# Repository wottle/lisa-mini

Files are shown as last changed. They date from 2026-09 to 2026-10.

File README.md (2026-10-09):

# Lisa Mini

A 3D-printable, Apple Lisa–inspired enclosure for building a mini all-in-one
around a [LisaFPGA](https://www.tindie.com/products/lisafpga/) board and an
11.6" 1080p widescreen LCD panel.

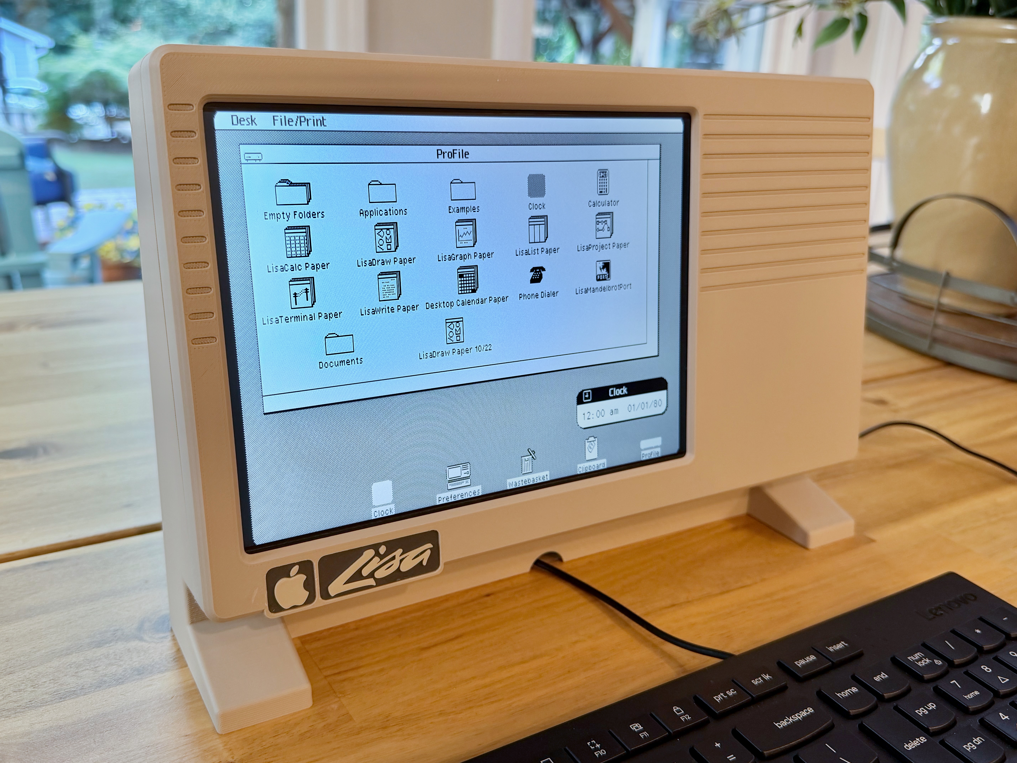
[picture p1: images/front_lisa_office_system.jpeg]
Lisa Mini running Lisa Office System


| | |
|---|---|
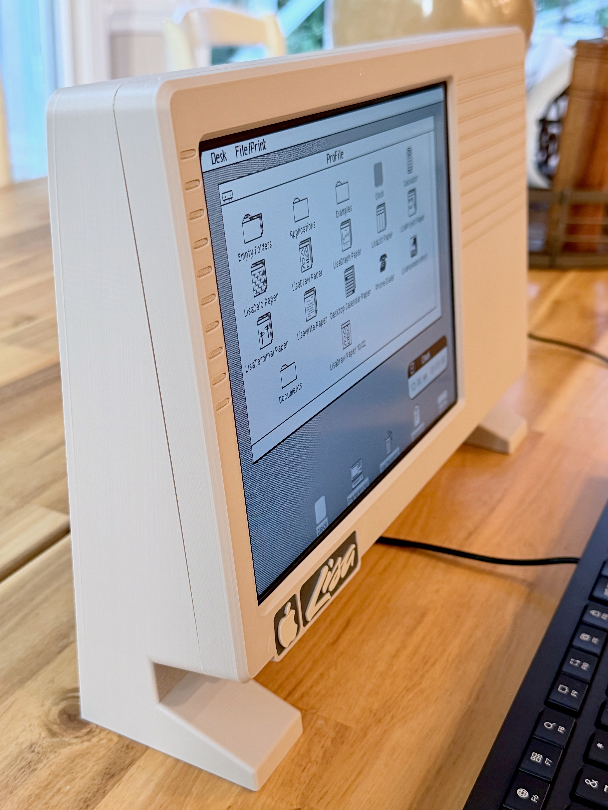
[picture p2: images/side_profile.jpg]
Side profile
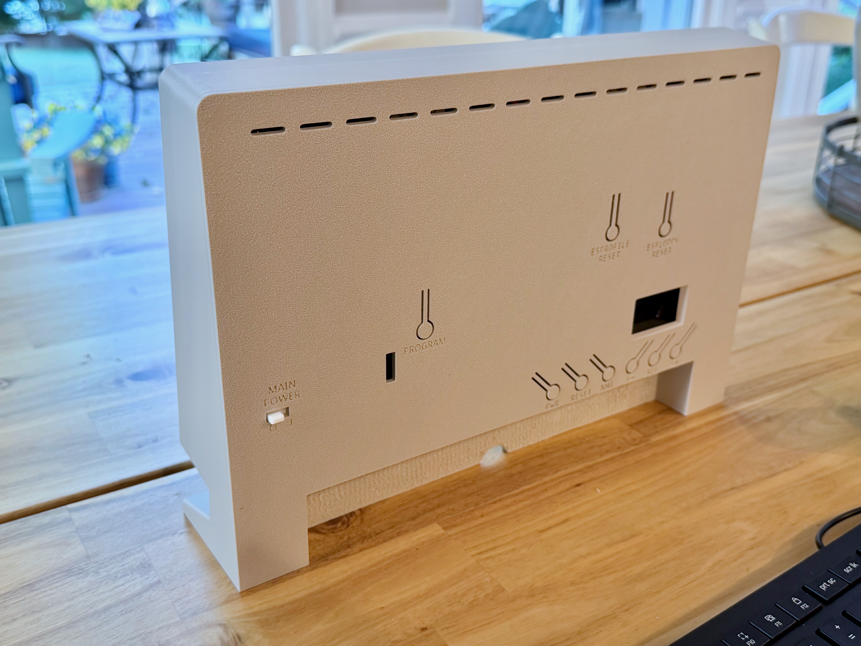
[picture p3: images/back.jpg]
Back, with labeled controls
|  |  |
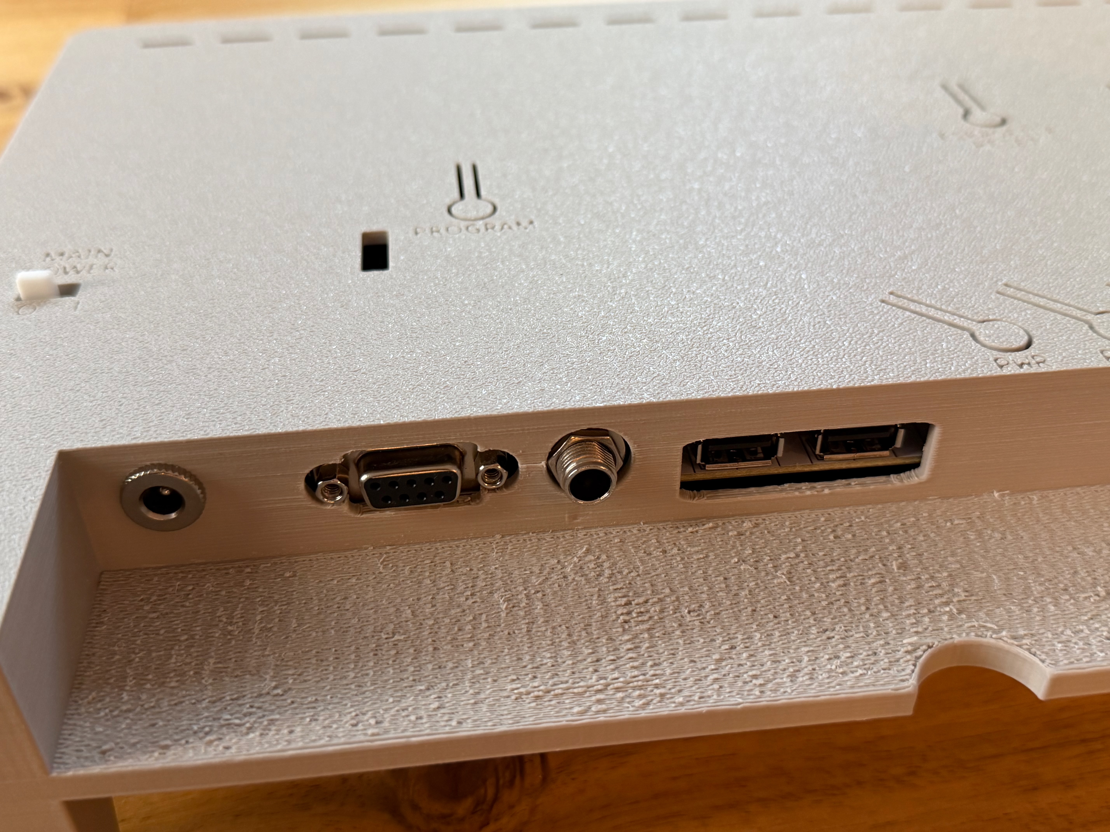
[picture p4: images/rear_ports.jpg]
Rear I/O
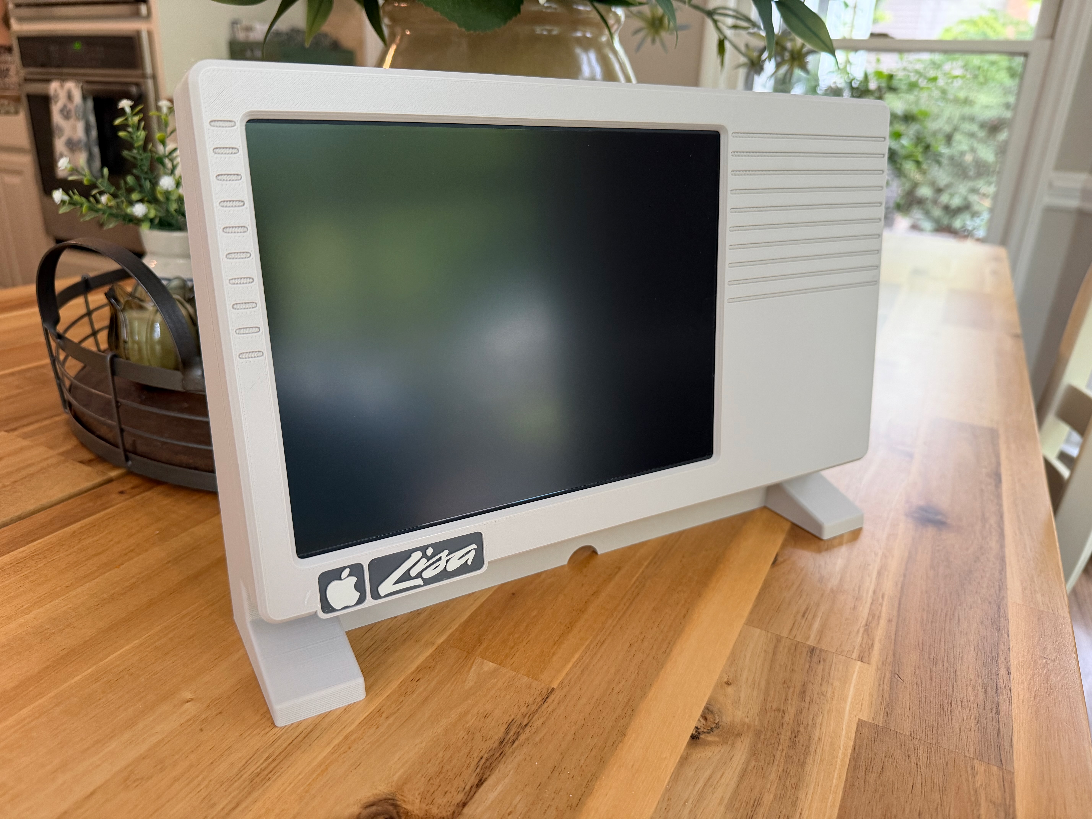
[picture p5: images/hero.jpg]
Angled front view
|  |  |

## About

This case is designed to house a LisaFPGA board — an FPGA-based
re-implementation of the original Apple Lisa — behind a compact modern LCD,
in an enclosure that echoes the look of the original 1983 Lisa: front vent
lines, a screen that leans back while the case stays vertical, and integrated
L-shaped feet with no visible seams between leg and case.

Designed for FDM printing, optimized to minimize supports where possible —
though both the front and back shells currently do need some supports
(see [Printing](#printing) below).

There's no built-in FloppyEmu, because the LisaFPGA has a floppy emulator
built in (ESFloppy) — no separate hardware needed. There are two designs
(see [Choose your design](#choose-your-design)). The stock one leaves the
LisaFPGA untouched and has cutouts for the ESFloppy control buttons and a
window to see the screen from the back, dressed up with a shroud
(`Lisa_Mini_ESFloppy_Shroud.obj`) since that opening sits well below the
back surface. The shroud's fit isn't perfect — it exposes a bit too much of
the area below the ESFloppy LCD, and needs some glue to stay in place. The
other design moves the ESFloppy screen and buttons, and the lit power
button, to the front, at the cost of soldering wires to the LisaFPGA.

## What's here

```
models/
  print-ready/
    common/      Parts printed for either design
    Lisa_Mini_With_ESFloppy_Screen_And_Buttons_On_Back/   Stock design: LisaFPGA left untouched
    Lisa_Mini_With_ESFloppy_Screen_And_Buttons_On_Front/  Front-mounted ESFloppy screen, buttons, and power button
  source/        Parametric OpenSCAD source + design notes
images/           Build photos and renders
docs/
  design_a/       ASSEMBLY.md and BOM.md for the ESFloppy-on-back design
  design_b/       ASSEMBLY.md and BOM.md for the ESFloppy-on-front design
  PRINTING.md     Slicer settings and printing notes
```

## Assembly video

Watch the [assembly video on YouTube](https://youtu.be/3yojjUhr7K4). It builds Design B, which
includes every step of Design A plus the ESFloppy and power button
modifications, so it works as a guide for either design.

## Choose your design

There are two versions of the case. **Pick one** and print its folder plus
the `common/` parts.

| | ESFloppy on back (stock) | ESFloppy on front |
|---|---|---|
| Folder | `Lisa_Mini_With_ESFloppy_Screen_And_Buttons_On_Back/` | `Lisa_Mini_With_ESFloppy_Screen_And_Buttons_On_Front/` |
| LisaFPGA modifications | None -- the board is left untouched | Solder wires to the ESFloppy buttons, move the ESFloppy screen, and move the lit power button to the front (remove the board's own power LED, solder wires to the board) |
| ESFloppy screen and buttons | Rear window and button cutouts, dressed up with a shroud | Front-mounted, with printed button caps and a screen clip |
| Power button | Button cutout on rear case | Lit button on the front, plus a master rocker power switch |
| Difficulty | Easier | Needs soldering to the LisaFPGA, plus extra parts (see BOM) |

## Parts to print

**Common parts (either design)** -- `models/print-ready/common/`

| File | Part |
|---|---|
| `Lisa_Mini_LCD_Mount_Clips.obj` | LCD retaining clips |
| `Lisa_Mini_Lisa_Logo_Plate.obj` | Lisa logo badge insert (see note below) |
| `Lisa_Mini_Manufacturer_Blank_Logo_Plate.obj` | Blank badge insert for the bezel's second holder (see note below) |
| `Lisa_Mini_Power_Switch.obj` | Cap over the LisaFPGA's power switch (the one that turns the whole device on and off) |
| `Lisa_Mini_Back_LisaFPGA_SD_Slot_Covers.stl` | SD slot covers for the back |

**ESFloppy on back** -- `models/print-ready/Lisa_Mini_With_ESFloppy_Screen_And_Buttons_On_Back/`

| File | Part |
|---|---|
| `Lisa_Mini_Front.obj` | Front bezel / LCD mount |
| `Lisa_Mini_Back_LisaFPGA.obj` | Rear shell, sized for the LisaFPGA board |
| `Lisa_Mini_ESFloppy_Shroud.obj` | Dresses up the rear ESFloppy screen opening, which currently sits well below the back surface |

**ESFloppy on front** -- `models/print-ready/Lisa_Mini_With_ESFloppy_Screen_And_Buttons_On_Front/`

| File | Part |
|---|---|
| `Lisa_Mini_Front_With_ESFloppy_Screen.obj` | Front bezel with the ESFloppy screen opening |
| `Lisa_Mini_Front_With_ESFloppy_Slot_Filler_Black.obj` | Black slot filler for the front |
| `Lisa_Mini_Back_LisaFPGA_ESFloppy_Moved_To_Front.obj` | Rear shell with no ESFloppy window or buttons |
| `Lisa_Mini_ESFloppy_Screen_Clip.obj` | Holds the ESFloppy screen |
| `Lisa_Mini_ESFloppy_Button_Cap.obj` | ESFloppy button cap |
| `Lisa_Mini_ESFloppy_Button_Inner_qty3.obj` | Button inner part (single part; print 3 copies) |
| `Lisa_Mini_ESFloppy_Button_Outer_qty3.obj` | Button outer part (single part; print 3 copies) |
| `Lisa_Mini_Power-Button.stl` | Front-mounted lit power button |

Each design has its own parts list and build guide: Design A
([BOM](docs/design_a/BOM.md), [assembly](docs/design_a/ASSEMBLY.md)) and
Design B ([BOM](docs/design_b/BOM.md), [assembly](docs/design_b/ASSEMBLY.md)).

**Logo plate note:** the front bezel has holders for two badge plates. This
repo includes the Lisa logo plate (`Lisa_Mini_Lisa_Logo_Plate.obj`) for one
and a plain, unbranded insert
(`Lisa_Mini_Manufacturer_Blank_Logo_Plate.obj`) for the other — deliberately
not shipping an Apple logo plate here to avoid distributing Apple's
trademarked logo. If you want an Apple logo in that spot, you'll need to
source or model your own.

## Editing the design

The parametric source (`models/source/lisa_modern_template.scad`) is an
OpenSCAD model of the case shell and covers the overall body/vent/leg
geometry. `models/source/lisa_design.md` documents the design reference
image this was built against and the reasoning behind the current shape —
read it before changing proportions.

Note: the `print-ready/` OBJs are further along than the `.scad` source
file. The OpenSCAD model produced a simplified starter shell, which was
then brought into TinkerCAD for significant additional work — mounting
points, port/switch openings, LCD clip geometry, and the logo plate —
that isn't reflected in the `.scad` file. Treat the `.scad` file as the
best starting point for overall shell/vent/leg proportions, not as a 1:1
source for the exact release files; there's currently no single parametric
source that captures the final printed geometry end to end.

## Software

The case's screen opening is sized for the original 9.7" 4:3 Lisa-style
window, but the LCD actually used is an 11.6" 1080p widescreen panel — the
image doesn't natively fill (or center in) that opening. This build
requires [wottle/LisaFPGA](https://github.com/wottle/LisaFPGA), a fork of
the LisaFPGA software that adds the ability to offset the displayed image
so it lands correctly within the case's opening. Stock LisaFPGA firmware
will not position the image correctly for this case.

**Flash it before assembling the case** — see "Before you start" in the
assembly guide for your design
([A](docs/design_a/ASSEMBLY.md#before-you-start),
[B](docs/design_b/ASSEMBLY.md#before-you-start)) for why.

## Power design notes

The original plan was to power the LCD controller board directly off a 5V
USB-C input. That controller board didn't work reliably on 5V USB-C — the
board was later damaged during troubleshooting, so it's unconfirmed whether
5V USB-C itself was the actual problem or just correlated with what killed
it. The working setup, and what the BOM/case now assume, is a single 12V
barrel jack input split across two buck converters into separate 5V lines
for the LisaFPGA and the LCD controller. If you try 5V USB-C directly into
the controller board, treat it as unverified and have a fallback plan.

The `Lisa_Mini_Power_Switch.obj` cap only switches the LisaFPGA — there's
no separate power switch for the LCD. The plan is to just pull the 12V
input when not in use, which cuts power to both.

## Printing

See [`docs/PRINTING.md`](docs/PRINTING.md). Quick summary:

- Wall thickness: ~2.4mm
- Infill: 15–20%
- Bed size: 350mm — the model is 330mm wide (front face down, back face up)
- Both front and back shells currently need supports — back for the skirt
  between the legs, front for the logo plate badge holder area
- Front/back shells press-fit together (alignment bumps, no screws);
  everything else uses M3x4mm screws

## License

Design files are released under
[CC BY-NC-SA 4.0](https://creativecommons.org/licenses/by-nc-sa/4.0/) —
free to share and remix for non-commercial use, with attribution, under the
same license. See [`LICENSE`](LICENSE).

## Also published on

- [Thingiverse](https://www.thingiverse.com/thing:7406982)
- [Creality Cloud](https://www.crealitycloud.com/model-detail/6aa08dfae6a4b4ead4eae24b?profileId=6aa08dfae6a4b4ead4eae251)

Not published to MakerWorld/Bambu — no Bambu printer currently has a bed
large enough for the 330mm-wide front/back shells.

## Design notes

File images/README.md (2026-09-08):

# Images

Drop photos and renders here:

- `hero.jpg` — main photo referenced from the top-level README
- Build/assembly photos referenced from `docs/ASSEMBLY.md`
- Render angles (front, 3/4, side profile, rear) for reference

Keep large source photos out of git history where possible (resize for web
before committing) — this repo has no LFS configured.

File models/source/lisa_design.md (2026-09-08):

# Lisa Mini — Design Reference

Source image: `lisa_design.png` (four views: front 3/4, angled front, side
profile, rear). This file captures what that image specifies, and how the
OpenSCAD model (`lisa_modern_template.scad`) maps to it, so future edits can
check back against the original intent instead of just the current code.

## Spec sheet (as stated in the image)

- **Width:** 330 mm (13.0 in)
- **Height:** 240 mm (9.4 in)
- **Depth:** 95 mm (3.7 in)
- **Weight (est.):** ~1.1 kg (2.4 lb)

**Design features called out in the image:**
- 9.7" 4:3 LCD (iPad panel), ~197×148mm visible area
- Inspired by the original Apple Lisa
- Optimized for 3D printing
- Minimal parts, no visible joins
- Front vent lines preserved
- Single PCB mount
- Integrated stand (legs)
- FloppyEmu slot (optional, not modeled)

**Printing notes called out in the image:**
- Designed for FDM printing
- No overhangs > 45°
- Snap-fit or screw assembly
- Wall thickness: 2.4mm
- Infill: 15–20% recommended

## What the image actually shows (visual detail, since dimensions alone
don't capture the shape)

- **Front:** screen roughly centered-left, with short horizontal vent
  ticks in a narrow strip on the left of the screen, and a noticeably
  wider block of the same vent lines on the right of the screen. Rainbow
  Apple logo bottom-right of the bezel (not modeled — decorative decal,
  out of scope). Vent lines start about level with the top of the screen
  and run for roughly the screen's upper half — they don't span the full
  case height.
- **Side profile:** the whole unit reads as a wedge — deep flat base at
  the feet, narrowing toward the top. Critically, the *screen leans back*
  (like the original Lisa's CRT housing) while the *back panel stays
  vertical*. The foot is clearly an L-shape: a slim, tapering riser
  attached under the case, meeting a flat pad that reaches forward along
  the floor — not a simple wedge or cone.
  - Now that the model's front actually leans back per the tilt fix, the
    case's real proportions (`body_depth_bottom=80`, `body_depth_top=45`,
    `case_height=189` currently) are shallower than the image's stated
    330×240×95 — see "Deliberate deviations" below.

### Legs: seamlessness is the critical detail

In the reference image, the leg is **not a bolted-on foot** — each side
panel of the case reads as *one continuous piece* that simply keeps going
past the bottom of the electronics housing, all the way to the floor, with
a subtle forward flare only right at the base (where it steps out from
under the case's own front-bottom overhang). There is no separate "foot"
element visually distinguishable from the case's own side — no step, seam,
or change of plane anywhere along that edge, front or back. This is the
single biggest reason the reference reads as "Lisa-like" rather than
"generic monitor stand": a leg that is numerically positioned to *match*
the case's dimensions still reads as an attached accessory if it's built
as an independent part; only a leg that *is* the case's own geometry,
merely continued, reads as seamless.

**First attempt (superseded):** anchored a separately-shaped L-bracket
(flat pad + tapered riser, its own independent width/depth parameters) so
its back face lined up with the case's rear-plane Z depth. This fixed the
back-face gap but still looked like "a leg" rather than "the case's own
side" — narrower than the case, inset from its edges, with its own corner
radius and taper rate that had to be separately chosen and matched. The
result was correct by the numbers but still visually read as a separate
part, which is exactly the complaint this section exists to prevent.

**Current approach:** the leg is a left/right edge strip of the case's own
outer shell, sliced to `feet_width` at each edge via `leg_side_shape()`,
continued from the case's own y=0 down to the floor — and — critically —
built and called *from inside the same `body_tilt()` rotation as the case
itself* (see `rear_shell()`). Because it shares the case's width reference
(flush with the case edges, no inset) and rotation, there is no separate
shape to keep in sync — the leg's continuity with the case is guaranteed
by construction, not by matching numbers. The forward flare "under the
protruding screen" falls out of the rotation for free: points below the
case's own y=0 rotate to increasingly negative Z (more forward) as they go
down, since the tilt pivots on the case's front-bottom edge.

**Wrinkle 1 (fixed): floor contact wasn't actually flush.** Rotating the
leg the same way as the case means its underside is no longer level (the
same rotation that tilts the screen back also tilts the leg's floor
contact, sagging the back lower than the front). The first attempt at
`required_lift()` computed the exact lift that puts the leg's lowest point
(the back-bottom corner) precisely at y=0 -- which sounds right, but means
the clip-to-floor intersection has *nothing left to cut*: the leg's
underside just grazes the floor at that one back corner, with the rest of
the underside (most visibly the front) tilted up in the air above it,
15mm+ in the numbers this was caught at. The fix: decouple how deep the leg
is *built* from where it's *lifted to*. `leg_side_shape()` now builds each
leg `feet_height + leg_extra_reach` deep (deliberately well past the
intended floor), `required_lift()` simply sets the case's front-bottom
pivot edge (the one point `body_tilt()` never moves) `feet_height` above
the floor, and `rear_shell()`'s y≥0 clip then slices through *solid*
material across the whole leg footprint -- verified by exporting
`rear_shell()` alone and confirming the vertices at the true minimum Y
span each leg's full width (`x: 0-40` and `290-330`, not a single point),
i.e. a genuine flat cut, not a corner graze.

**Wrinkle 2 (fixed): rounding doubled up at the seam.** `leg_side_shape()`
originally reused the case's own `rounded_prism` (same `corner_radius`),
which rounds the leg's own top edge right where it meets the case --
directly on top of the case's own bottom-corner rounding, at the same Y.
Two independently-rounded corners stacked at one seam reads as a pinched
double-curve rather than one clean transition. Fixed by dropping rounding
from the leg entirely (a plain `cube()`, no radius) and raising it up by
`leg_overlap` (`corner_radius + 0.2`) past the case's own y=0, so the
leg's sharp material fills in solid over the case's rounded corner instead
of showing its own curve there -- the only rounding left along that edge
is wherever the case is rounded on its own (its top corners), unrelated to
the leg. `tilt_angle()` was pulled out of `body_tilt()` into its own
function so `required_lift()` and `leg_side_shape()` can't drift out of
sync with the case's own tilt.

**The L profile itself.** Up to this point the leg was still a solid
block (flush back, flush width, floor-clipped, seam-hidden -- but no
notch). Giving it the actual L shape means cutting away the top-front
mass, per this shape (constant across the leg's width, via
`notch_profile()`):
- A **riser** segment at the back, `leg_riser_depth` thick, running from
  the case down by `leg_riser_drop`. Built as a plain constant-Z cut (no
  trig at all): since the whole leg shares the case's own `body_tilt()`
  rotation, any constant-Z segment automatically stays parallel to the
  case's own tilted front after that shared rotation -- it can't help but
  match the display's angle.
- A **bend-to-foot** segment continuing down by `leg_toe_drop` to the
  foot's front tip, meant to read as `leg_foot_slope` degrees below
  horizontal in the *final*, post-tilt view. This one isn't free: a
  locally-horizontal cut does not come out horizontal after the same
  rotation that tilts the display -- it comes out sloped at exactly
  `tilt_angle()` from horizontal, since the rotation tips whatever's
  locally flat right along with everything else. Solving for the local
  slope that cancels that and adds the requested tilt gives a clean
  closed form: `local_slope = tan(tilt_angle() + leg_foot_slope)` (derived
  via the angle-addition identity; `leg_foot_slope=0` would give a
  perfectly level result).
- Below the toe, the cross-section is constant again, straight down
  through the floor (with `leg_extra_reach`'s overshoot for the floor
  clip, unchanged from before).

Implementation note: since `polygon()`/`linear_extrude()` can only extrude
along OpenSCAD's own Z axis, and this profile needed to run along the
leg's *width* (X) instead, `leg_side_shape()` defines the profile in
`[Y, Z]` pairs and remaps axes with `rotate([0,90,0]) rotate([0,0,90])` so
the final solid comes out as `(X, Y, Z) = (extrude parameter, Y, Z)` --
verified against an isolated test polygon (checking the exact X/Y/Z value
sets in the exported STL) before relying on it, since an axis-remap
rotation is an easy place to silently mirror or scramble a shape.

**Wrinkle 3 (fixed): the leg's back edge wasn't flat.** The notch
profile's back edge was a plain constant-Z cut, same trick as the riser
segment above (see riser bullet) — which is exactly the problem: that
trick relies on staying *parallel* to the case's front face after
rotation, but the case's actual rear panel is supposed to come out **flat**
(perpendicular to the floor, not parallel to the tilted front — see item
5 in the log below). A constant-Z leg-back only coincides with that flat
plane at the pivot (y=0); moving up the leg's height, it drifts further
off, parallel to the front's tilt instead. Fixed the same way as Wrinkle
1 (floor contact): overshoot first, then clip flush in the *global*
frame. `leg_rear_extra_reach` pushes the back edge deep enough that
`rear_plane_z()` — the global Z where the case's own tapered rear face
lands after `body_tilt()` (`body_depth_bottom * cos(tilt_angle())`, since
that's precisely the rotation that flattens the taper line into a flat
plane) — always cuts through solid material, never grazing a corner.
Verified by exporting `rear_shell()` alone and confirming every leg-back
vertex collapses to that single Z value rather than a spread of values.

**Rounded the leg's exposed edges — profile corners AND side caps.** The
knee (where the riser bends into the foot), the foot's front tip, and the
leg's left/right side faces (both the riser's and the foot's) were all
sharp — reads as "cut out of a block" rather than a finished part, and
sharp edges print worse than filleted ones. First pass only rounded the
knee/toe (via the same dilate/erode `offset()` trick as `rounded_2d()`,
applied to the 2D notch polygon) since that only rounds edges that run
*along* the extrusion axis (X, the leg's width) — it can't touch the
edges at the leg's two ends, where those front faces meet the flat
side-cap planes.

Rounding the side-cap edges too needs an actual 3D fillet, done via the
standard "erode along X, then `minkowski()` with a sphere" rounded-box
trick: build the core extrusion inset by `leg_edge_round` on each end
(`feet_width - 2r` wide, shifted in by `r`), then `minkowski()` it with
`sphere(r)`. For any of the core's flat faces, minkowski with a sphere
just offsets that face outward along its own normal by `r` — so insetting
by `r` first and growing by `r` after lands the two side caps back at
exactly `x=0`/`x=feet_width` (no residual bulge needing a clip), while
every edge/corner in between — the knee, the toe, *and* now the side-cap
edges — comes out genuinely filleted, all from one `leg_edge_round`
radius. This replaced the earlier 2D-only `rounded_notch_2d()` /
`offset()` approach entirely (real 3D rounding subsumes it; using both
would double up).

The back (rear-plane) and floor edges are deliberately left un-inset —
minkowski still puffs them outward by `r` too, but that's harmless: as
established above, they're already overshoot material clipped exactly
flush by the global half-space cuts regardless of the shape fed into
them, and the existing margins (`leg_extra_reach`, `leg_rear_extra_reach`)
comfortably exceed `leg_edge_round`. Verified both that the fillets show
up correctly (rendered close-ups of a single leg and of the assembly) and
that the floor/back flush cuts survived unchanged (re-checked the
exported STL: the leg's back face is still a single flat Z value, and the
floor contact is still a full-width flat patch, just with its two front
corners now rounded instead of square).
- **Rear:** flat vertical panel, full-width row of short horizontal vent
  slats near the top, and a lower recessed strip for Mouse / Keyboard /
  USB ports and their labels, plus the feet visible at the base. The model
  currently stands in for that lower strip with a plain rectangular I/O
  bay (`io_bay_*` params) rather than modeling individual ports/labels —
  see item 15 below; real port cutouts and labels are meant to return once
  the board layout is designed.
- **Corners:** rounded on every visible edge, front and back consistently
  (not just the front bezel).
- **No chin, no visible seam** at the bottom of the screen bezel — the
  image's front face is one continuous surface from top to bottom.

## How the model maps to this (session history, newest last)

1. **Base template → resized to spec.** Started from a generic flat-front
   Lisa-style starter template (`lisa_modern_template_README.txt`
   describes the original). Resized to 330mm width, adjusted height, and
   widened/repositioned the right vent grille to match "narrow left,
   wide right."
2. **Wedge body + tapered legs.** Replaced the flat-depth body with a
   tapered shell (deep at the floor, shallow at the top) and tapered fin
   feet, to get the wedge silhouette from the side-profile image.
3. **Fixed a real bug:** `rounded_2d()`'s `offset(r=r)` /
   `offset(delta=-r)` rounding pattern silently produces empty geometry
   when `r` equals exactly half the shape's narrow dimension — meaning no
   vent slots were ever actually being cut in the original template. Fixed
   by keeping rounding radii strictly under half the narrow dimension.
4. **Corrected vent/screen left-right mapping and case proportions.**
   Rendering with a camera matching the actual OpenSCAD viewing angle
   showed the vent widths were swapped from the image (wide should be
   right, narrow left) and the case was much taller than the screen
   needed — fixed both, and later renamed the vent variables so their
   names match their actual rendered side.
5. **Front tilts back, rear stays flat — via rotation, not shear.** The
   image's screen leans back while the back panel is vertical. A Z-only
   shear achieves the lean but leaves the top/bottom caps perpendicular
   to the *original* vertical axis instead of to the tilted front, which
   looked glued-on. Switched to a true rotation (`body_tilt()`) pivoting
   on the front-bottom edge, which keeps the top/bottom faces
   perpendicular to the tilted front (matching the image's continuous
   surface) while the rear stays flat, by construction (same taper rate
   that tilts the front by the right amount also cancels the rear's
   slope to zero).
6. **Removed the chin, unified corner rounding.** The template had a
   protruding lower "chin" not present in the reference image, and the
   rear shell rounded a different plane than the front bezel (so corners
   didn't match front-to-back). Removed the chin; rebuilt the rear
   shell's taper as a full rounded box trimmed by an unrounded wedge
   cutter, so it shares the front bezel's exact corner rounding.
7. **Chamfered the screen opening's front edge** — a detail not visible
   at the image's resolution, but a reasonable real-world softening of
   the sharp edge (`screen_bevel`).
8. **Front bezel as a cap, not a butt-joint (later reworked — see #13).**
   Original front/rear pieces just met at a flat seam. Gave the front
   bezel a skirt (`front_cap_skirt()`) that friction-fits over the rear
   shell's exterior with a small clearance, so it now caps over the back
   instead of butting up against it — "minimal parts, no visible joins"
   (image's design-features list) driven by an actual physical assembly
   method rather than glue.
9. **Legs redesigned as L-brackets, merged into the back piece.** Per the
   side-profile image: a flat floor pad plus a tapering riser meeting the
   case underside, not the earlier simple tapered fin. Folded into
   `rear_shell()` (kept outside `body_tilt()` so they stay upright) so
   the legs print as one piece with the back — matching "minimal parts."
   First attempt tapered the riser's depth as well as its width, which
   made the riser's back face a diagonal ramp (read as a wedge/cone, not
   an L) — fixed by holding riser depth constant and tapering width only.
10. **Legs anchored to the case's actual rear plane (superseded by #11).**
    Added `leg_back_z()` and anchored `foot_shape()` to it, so the leg's
    back face lined up with the case's own (flat, post-tilt) rear surface
    instead of an arbitrary local depth. Fixed the back-face gap, but the
    leg was still an independently-shaped part positioned to match the
    case rather than a literal continuation of it — still read as "a leg"
    rather than "the case's own side," per user feedback after seeing it
    rendered.
11. **Legs rebuilt as literal continuations of the case's own side shell.**
    Replaced the independent L-bracket (`foot_shape()`, `tapered_foot()`,
    `footprint_slice()` — all removed) with `leg_side_shape()`: a
    left/right edge strip of the case's own `rounded_prism`, continued
    below the case's y=0 by `feet_height`, called from *inside*
    `rear_shell()`'s `body_tilt()` so it shares the case's exact rotation
    instead of being built upright and positioned to match. `tilt_angle()`
    was pulled out of `body_tilt()` into its own function so
    `required_lift()` (replacing the old fixed `feet_height +
    body_floor_gap` in `body_position()`) can compute exactly how far to
    lift the tilted assembly so its lowest point (the legs' back-bottom
    corner, which sags below the front due to the rotation) lands at
    y=0 — `rear_shell()` then clips to y≥0 for a flat floor cut. See
    "Legs: seamlessness is the critical detail" above for the full
    reasoning and why the previous entry's fix wasn't sufficient.
12. **Legs given their L-profile notch, then flush back + rounded edges.**
    Carved the top-front mass away per `notch_profile()` (riser matching
    the display's angle, foot sloped per `leg_foot_slope`). Follow-up fixes
    once the notch was visible: the leg's back edge was parallel to the
    tilted front instead of flat like the case's real rear panel (fixed
    with the same build-deep-then-clip trick as the floor, via
    `leg_rear_extra_reach` + `rear_plane_z()`), and the exposed knee/toe
    corners were sharp (rounded via `rounded_notch_2d()`, which only
    rounds convex corners so the hidden seam corner stays untouched). See
    "Wrinkle 3" and "Rounded the leg's exposed front corners" above.
13. **Front cap skirt reworked to slide inside the back piece, not wrap
    around its outside.** The original `front_cap_skirt()` (item 8) sized
    itself relative to a *grown* copy of the case's own tapered exterior
    (`grown_tapered_shell()`, since removed) — mechanically sound (a real
    friction-fit lip) but visually wrong: growing the exterior necessarily
    makes the front piece's footprint wider, and differently cornered,
    than the back piece's, which read as a visible stepped ring right at
    the seam — exactly the opposite of "minimal parts, no visible joins."
    User feedback: the cap should keep the *same* outer dimensions as the
    front/back pieces everywhere, sliding inside the back piece's own
    interior instead. Fixed by sizing the skirt off the rear shell's
    hollow interior cavity footprint (`case_width/height - 2*wall_thickness`,
    corner radius `corner_radius - wall_thickness` — see the "Hollow
    interior" cut in `rear_shell()`) shrunk by `cap_clearance` per side,
    rather than off a grown copy of the exterior. Since the interior
    cavity happens to be untapered (a plain `rounded_cut`, not
    `tapered_shell`), the new skirt is just a straight rounded-rect ring —
    simpler than the old version, and needs no taper-aware helper at all.
    Verified numerically: exporting the front piece alone now shows its
    X bounding box is exactly `[0, case_width]`, identical to the back
    piece, with no protrusion.
14. **Front/back depth split made adjustable via `front_thickness`, and a
    real redundancy fixed along the way.** User wanted the front piece to
    read as a visibly deeper section (more of the case's total depth) and
    the back piece correspondingly shallower, with the *overall* case
    depth unchanged. Tracing through `rear_shell()` turned up a
    pre-existing bug that was blocking this: the outer tapered shell was
    built from the *full, untrimmed* `body_depth_bottom`/`body_depth_top`
    (via a `translate(-(front_thickness+assembly_gap))` pre-shift that
    exactly cancelled the outer wrapper's `+(front_thickness+assembly_gap)`
    translate) — meaning the rear piece's outer rim always re-modeled the
    *entire* case depth starting from the true front tip (global z=0),
    fully coincident with and redundant to the front piece's own rim over
    `[0, front_thickness]`, regardless of what `front_thickness` was set
    to. Every *interior* feature (the hollow cavity, rear recess, vent
    slats, port cutouts) was already correctly anchored to
    `local_exterior_z(y)` — i.e. already built assuming the rear piece's
    own local frame starts at the split line — so only the outer rim
    itself was out of step with that intent.

    Fixed by building the outer tapered shell directly from
    `local_exterior_z(0)`/`local_exterior_z(case_height)` (the total taper
    minus `front_thickness+assembly_gap`) with no pre-shift needed at all.
    Since both endpoints shrink by the same constant, the far (true rear)
    face — and thus the case's total depth — is completely unaffected;
    only the near face moves back from the true front tip to the split
    line, exactly matching the front piece's own extent. `front_thickness`
    (5.5 → 16 as of this writing) is now a genuine "how much of the total
    depth belongs to the front piece" dial, bounded above by needing
    `interior_depth` (which shrinks as `front_thickness` grows) to stay
    comfortably deeper than `cap_depth`. Verified via `echo()`: total
    depth at y=0 and y=case_height reproduce `body_depth_bottom`/
    `body_depth_top` exactly regardless of `front_thickness`.
15. **Individual port holes and labels pulled out, replaced with a plain
    I/O bay placeholder (later reshaped — see #16).** The mouse/keyboard
    (round) and USB (slot) cutouts, their "MOUSE"/"KEYBOARD"/"USB"
    engraved labels, and the narrower label recess they sat in were all
    removed — the user wants to design the actual board layout and
    connector placement later rather than keep nominal placeholder
    positions/sizes around. Replaced with a single plain rectangular
    pocket (`io_bay_w/h/d/y/r`) at bottom-center: 280mm wide, 50mm tall,
    cut 25mm into the back panel, sitting a bit above the floor. Used the
    same flat-cut-at-center-Y technique the old label recess used (a
    single flat `rounded_cut` rather than following the taper across the
    bay's own height). The top vent slat row is unaffected.
16. **I/O bay widened to match the leg gap and opened down to the floor —
    which exposed a real angle bug in the flat-cut technique item 15
    used.** User wanted the bay's width to match the gap between the two
    legs exactly, and its bottom to reach the floor so it reads as one
    continuous opening running down between the legs, rather than a
    pocket floating mid-panel. Straightforward part: `io_bay_w` became
    `case_width - 2*feet_width` (derived, so it stays in sync with
    `feet_width`) positioned starting at `x=feet_width`; `io_bay_y` was
    dropped since the bottom is now always the floor (0) by design; the
    footprint overshoots below y=0 by `io_bay_r` (same trick as the leg's
    knee/toe rounding hiding its unwanted corner) so only the *top* two
    corners round over, leaving a clean flat cut where the opening meets
    the case's own bottom edge.

    Reaching the floor is what surfaced the bug: user reported "the cut in
    is set to mirror the screen's angle, where it should be vertical like
    the back panel." The old flat `rounded_cut` for io_bay's depth was a
    plain constant-Z boundary in the pre-tilt frame — exactly the same
    mismatch `leg_rear_extra_reach`/`rear_plane_z()` fixed for the leg's
    back edge (see "Wrinkle 3" above): a constant-Z plane comes out
    parallel to the tilted *front* face after `body_tilt()`, not
    vertical/parallel to the true (flat) back panel. At the bay's old
    small height (31mm) and away from the floor, this was subtle enough to
    go unnoticed; stretched to 50mm and now visible all the way to the
    floor, it read clearly as a slanted gouge.

    Fixed using the *other* technique already established in this file for
    exactly this problem — the one `tapered_shell()`/`wedge_cutter()` use
    for the case's own true rear face — rather than the leg's
    overshoot-and-clip approach: build the pocket's Z-bounds as the
    `difference()` of two `wedge_cutter()`s sharing `y=[0,io_bay_h]`, one
    for "out to the true surface (+0.3 overshoot)" and one for "out to
    `io_bay_d` short of it." Since `wedge_cutter()`'s taper is linear and
    exactly matches `local_exterior_z(y)`'s own slope by construction (both
    endpoints are set from that same function), the resulting slab tracks
    the true surface's taper across the bay's height instead of using one
    flat value — coming out genuinely flat/vertical after rotation.
    Verified directly (not just by inspection) by probing where the
    pre-tilt points `(y=0, floor_z(0))` and `(y=io_bay_h, floor_z(io_bay_h))`
    land after `body_position()+body_tilt()`: both mapped to the *same*
    global Z, confirming the floor is flat; also confirmed visually from a
    straight-on rear view, where the opening's boundary lines are
    perfectly horizontal across the full width instead of sloped.
17. **Fixed a hairline sliver left at the floor.** After #16, user spotted
    a thin sliver of material left over right at the bottom of the
    opening. Cause: the two `wedge_cutter()`s only spanned `y=[0,io_bay_h]`
    (matching `io_bay_h` exactly) — but `wedge_cutter()`'s `hull()` doesn't
    extend past its own `y=[0,h]` domain at all, so it had nothing to
    offer below `y=0`, right where the footprint's rounding-hiding overshoot
    (`io_bay_r` below the floor — see #16) needed something to intersect
    against. Fixed by extending both wedge_cutters' domain down to
    `y=-io_bay_r` too (matching the footprint's own overshoot exactly), so
    the cut has a genuine safety margin below the floor instead of
    stopping precisely at `y=0`. Verified no facets at all remain in that
    region of the exported STL (previously the sliver would have shown up
    as small facets right at `y≈0`).
18. **Foot slope made dramatically steeper to match the original Lisa.**
    User could tune the back (riser) height fine via `feet_height`, but
    the front (toe) always stayed too tall — the foot read as a fairly
    uniform-thickness pad rather than the original's pronounced
    thick-at-back/sharp-at-front wedge. Root cause, found by numerically
    probing where the knee and toe points land in the final (post-tilt)
    frame: `leg_foot_slope` (6° at the time) really was only producing a
    ~4mm height difference between knee (~16.8mm) and toe (~12.75mm) —
    correct per its definition, but too shallow to read as dramatic. The
    real ceiling on how low the toe can go is set by `leg_toe_drop` (a
    pre-tilt Y-distance, capped at roughly `leg_toe_drop*cos(tilt_angle())`
    of actual final height drop as `leg_foot_slope→90°`) — `leg_foot_slope`
    then trades off between spending that ceiling on forward reach
    (shallow angle) versus height drop (steep angle). At the old
    `leg_toe_drop=12`, no angle could produce more than about 11.7mm of
    drop, nowhere near enough. Fixed by increasing both together —
    `leg_toe_drop` 12→20, `leg_foot_slope` 6°→15° — chosen by probing
    several combinations and picking one that dropped the toe to ~5.4mm
    (from a ~16.8mm knee, roughly 3x taller in back) while keeping
    comfortable clearance above y=0 (combinations pushing much further,
    e.g. `leg_toe_drop=30`+, drove the toe's pre-clip position *below* the
    floor entirely, which would've just been clipped away flat rather than
    forming a sharp point). Re-verified both the floor-flush and
    back-flush fixes (items in "Legs: seamlessness…" above) still hold
    unchanged after this — they don't depend on these two params.
19. **Front bezel's outer perimeter edge chamfered at 45 degrees.** User
    wanted the sharp edge running around the front piece (where the flat
    front face meets its sides) softened — distinct from `screen_bevel`,
    which only softens the screen cutout's own edge, not the case's outer
    edge. Added `chamfered_prism()`, the mirror image of the existing
    `beveled_cut()` trick: instead of hulling a *larger* ring at the true
    surface down to the true-size opening (softening a cutout from the
    outside in), it hulls a *smaller*, inset footprint at z=0 out to the
    true-size footprint at `z=front_edge_bevel` (softening a solid's own
    outer edge from the inside out). Equal inset and depth
    (`front_edge_bevel=2.5`) is what makes it read as 45 degrees rather
    than some other angle. Used in place of the plain `rounded_prism()`
    for the front face's outer shape in `front_bezel()`, with the screen
    opening and vent cuts subtracted from it exactly as before.
20. **Front vent lines made shallow decorative grooves instead of
    through-cuts.** They were cutting all the way through `front_thickness`
    (now 16mm — see item 14 — so this became very visible), showing the
    hollow interior behind them instead of reading as surface detail.
    Added `vent_depth=0.8` and changed `vent_slots()`'s cut depth from
    `front_thickness + 0.5` to `vent_depth + 0.2` (small overshoot past
    z=0 only, no longer reaching anywhere near the back of the piece).
21. **Rear vent slats found to be blind grooves instead of the through-cuts
    they were meant to be — a real, pre-existing bug.** User asked to
    confirm/keep the rear vents as through-cuts (unlike the front ones,
    fixed the opposite way in item 20) and then caught that they in fact
    weren't. Their depth was `back_thickness + 1.5`, starting
    `back_thickness` behind the true exterior surface — correct *only* at
    `y=case_height`, the single point `interior_depth` was conservatively
    sized from (see the "Conservative (untapered) interior cavity depth"
    comment on `interior_depth` above). `vent_row_y = case_height - 16`
    sits enough below that for the wedge taper to leave noticeably more
    wall material there — the fixed `back_thickness` depth fell short of
    the hollow cavity by a couple mm, leaving blind grooves. Fixed by
    deriving the cut's span from the actual local geometry instead of a
    constant: start at `interior_depth` (the hollow's own true boundary,
    regardless of Y) and run out to `local_exterior_z(vent_row_y)` (the
    true exterior surface at that specific Y), each with a small overshoot
    margin (0.5) baked in on first pass, then doubled after the user
    still spotted a sliver on inspection. Verified by intersecting the
    exported back shell against the vent cut's own exact target volume —
    empty, confirming nothing is left uncut.
22. **Added a solid skirt between the legs, closing off what was open
    air.** User felt the open gap between the legs (below the case's own
    bottom edge, above the floor) didn't match the original Lisa, which
    reads as having a solid closed underside — and noted it'd also hide
    any wiring routed down through the future I/O bay. Added `leg_skirt()`
    (`skirt_thickness=3`), positioned "flush with the back of the port
    cutout" by reusing the I/O bay's own floor formula
    (`local_exterior_z(y) - io_bay_d`) continued down through the legs'
    own Y-range instead of the bay's — the two are coplanar by
    construction, forming one continuous flat surface across the
    transition rather than a step.

    First implementation used the same `difference()` of two
    `wedge_cutter()`s io_bay's own cut uses (one wedge for the outer
    bound, one for the inner, `skirt_thickness` apart) — this is exactly
    the technique that works for io_bay, but broke here: `wedge_cutter()`
    computes volume from Z=0 up to its taper, appropriate when the shape
    is meant to start at the origin (io_bay's cut does), but for the
    skirt both wedges' d-values differ by only `skirt_thickness=3mm` over
    a much larger `h` and Z magnitude (tens of mm) — exactly the kind of
    near-cancelling subtraction of two similar large solids that lost
    precision in CGAL's boolean, coming back as two degenerate slivers
    (matching `wedge_cutter()`'s own internal 0.1mm end-slabs) with
    nothing in between. User caught this immediately ("shifted forward
    and... a second very thin slice floating in front of the legs").
    Fixed by building the already-thin cross-section directly instead:
    `hull()` of two 0.1mm-in-Y slabs, each already the correct
    `skirt_thickness`-thick slice at that Y, interpolated smoothly between
    them — the same *spirit* as `wedge_cutter()` (a hull of two thin
    reference slabs) but without ever computing a large intermediate
    volume to subtract away. Also needed a bigger X overlap into the legs
    than a simple float-noise epsilon: `leg_side_shape()`'s minkowski
    rounding (`leg_edge_round`) pulls the leg's actual material back from
    its nominal edge near that corner, so the overlap has to reach past
    that pullback (`leg_edge_round + 0.5`), not just guard against
    coincident-face noise.

    Along the way, confirmed (by rendering with `leg_skirt()` commented
    out) that a small pre-existing concave notch visible at the leg/bay
    junction from certain steep angles is unrelated to the skirt — an
    inherent, previously-hidden feature of the leg's own L-profile that
    the I/O bay's recess exposes to view from some angles. Left alone
    (out of scope here); the model is confirmed manifold either way.
23. **Skirt depth made adjustable (`skirt_offset`).** Even with the geometry
    bug in item 22 fixed, the skirt sitting exactly flush with the I/O
    bay's floor still read as too far forward (too close to the true
    exterior surface / the legs' own front faces) once actually seen
    correctly positioned. Added `skirt_offset` on top of the flush
    position from item 22 (`local_exterior_z(y) - io_bay_d - skirt_offset`):
    positive moves the skirt forward, toward the true exterior surface;
    negative moves it backward, deeper into the case. Set to `-10` as a
    first pass, recessing the skirt visibly behind the legs' own front
    faces rather than sitting flush with them.
24. **`leg_edge_round` matched to `corner_radius` (partial fix, see item
    25).** User noticed a seam where the leg meets the case body. Cause:
    the case's own corner rounding (`corner_radius=7`) and the leg's edge
    fillet (`leg_edge_round`, 3 at the time — see item 12) are two
    independent rounding operations that happen to sit right next to each
    other vertically (the leg's own X-end cap fillet is the natural
    continuation, below `y=leg_overlap`, of the case's corner rounding
    immediately above it) — but with different radii, so the curvature
    visibly changed right at that boundary instead of flowing
    continuously. Fixed by deriving `leg_edge_round` from `corner_radius`
    instead of hardcoding it separately. This turned out to be incomplete
    — see item 25 — and the user has since retuned `leg_edge_round` back
    to its own independent value (2) once item 25's real fix was in place.
25. **Leg's top edge clipped flush instead of left to float — fixes both
    the remaining seam and a real interior-clearance bug.** Matching the
    radius (item 24) didn't fully fix the seam, and increasing
    `leg_edge_round` made the legs protrude up into the interior cavity
    space. Root cause of both: the leg's `minkowski()` rounding pushes
    *every* boundary outward by `leg_edge_round`, including the top edge
    at `y=leg_overlap` — but unlike the back and floor edges (already
    protected by `rear_shell()`'s global half-space clips, see items 6–7
    and "Wrinkle 1"), nothing ever trimmed that top overshoot back down.
    At small radii this stayed harmlessly inside the case's own solid
    corner; at bigger radii it reached past where the interior hollow
    begins, adding unhollowed material into space meant to stay clear for
    the PCB/LCD bracket — a real bug, not just cosmetic. It also could
    never have fixed the seam on its own: the case's corner is a simple
    constant-radius sweep in Z, while minkowski gives the leg a *compound*
    3D fillet there, so no radius choice makes those two curvature types
    match — only clipping the leg flat before that compound curvature
    becomes visible actually resolves it.

    Fixed with the same build-it-oversized-then-clip-flush technique used
    for the back and floor: `leg_side_shape()` now intersects the
    minkowski result with a `y <= leg_overlap` half-space, in the same
    local (pre-tilt) frame the case body itself uses — safe here (unlike
    a naive constant-Z cut) because we're not trying to match some
    externally-defined flat plane, just capping the leg's own extent to
    stay consistent with the case's own coordinate frame. Only the
    (currently unrounded) top region is affected; the knee, toe, and
    X-end fillets are all well below `y=leg_overlap` and untouched.
    Verified directly: with `leg_edge_round` deliberately set to 7 (matching
    `corner_radius`, the case that triggered the bug), the isolated leg's
    max Y came back as exactly `7.2` (`leg_overlap`) regardless — confirms
    the clip holds regardless of rounding radius, not just for whatever
    radius happened to be set at test time.
26. **Interior hollow cavity reshaped to track the taper, for a constant
    (not ballooning) wall thickness.** User printed a test piece and found
    the back wall got noticeably thicker toward the base than at the top
    — using far more material than a `back_thickness`-thick wall needs to
    be sturdy. This was fully intentional in the original design (see the
    old "Conservative (untapered) interior cavity depth" comment,
    documented back in the early spec-mapping log): `interior_depth` was a
    single, Y-independent cut depth, deliberately sized to the shallowest
    point (the top, `y=case_height`) so it would never poke through the
    sloped rear wall — safe, but it meant the cavity stayed the same
    absolute depth everywhere while the exterior kept taper *deeper*
    toward the base, leaving progressively more (unneeded) solid material
    behind it lower down.

    Fixed by replacing the flat `rounded_cut()` hollow with
    `tapered_shell()` — the exact same technique the case's own outer
    shell already uses for its true (tapered) rear face — driven by a new
    `interior_boundary_z(y) = local_exterior_z(y) - back_thickness`
    function. Since `tapered_shell()`'s linear interpolation is set from
    the true endpoint values of this same linear function, it reproduces
    `interior_boundary_z(y)` exactly at every Y in between, not just the
    two ends. `interior_depth` (used elsewhere as the conservative
    minimum-clearance reference for `cap_depth`) is now simply
    `interior_boundary_z(case_height)` — the same value it always
    represented, just derived rather than hand-picked, since the
    shallowest point is still exactly where the old constant was sized
    from. The rear vent slats (item 21) also switched from referencing
    the old constant to `interior_boundary_z(vent_row_y)`, since the
    hollow's boundary is no longer Y-independent — this actually
    simplified that fix too: with the cavity now genuinely tracking the
    taper, the vent depth really is just `back_thickness` plus overshoot
    at every Y, rather than needing a special-cased non-constant formula.
    Verified numerically: wall thickness computed at both
    `y=wall_thickness` (near the base) and `y=case_height-wall_thickness`
    (near the top) both came back as exactly `3` (`back_thickness`) —
    confirms the taper-tracking is exact, not approximate.
27. **Legs still protruding into the interior — item 25's clip wasn't
    enough on its own; a second bug.** After item 26, the user reported
    the legs still poked into the interior cavity space. Root cause: the
    interior hollow cut has *always* only been subtracted from the case
    body's own `difference()` — legs are `union()`-ed in afterward,
    completely untouched by that cut. Item 25's `y<=leg_overlap` clip
    stops the leg from growing past the case's own seam as
    `leg_edge_round` grows, but it has no idea where the interior cavity
    begins — and since legs are `feet_width` (35mm) wide, far wider than
    `corner_radius` (7mm), their entire overlap region (`y` from 0 to
    `leg_overlap`, the *full* leg width in X) was unconditionally solid,
    plugging a large swath of genuine interior clearance space wherever
    it geometrically overlapped the hollow — not just the small
    rounded-corner sliver the overlap is actually meant to fill.

    Fixed by restructuring `rear_shell()` so the interior hollow cut
    applies to the *whole* union (case body + legs + skirt) instead of
    just the case body: `union() { case_body; legs; skirt; }` is now
    itself wrapped in `difference() { ...; hollow_cut; }`, with the hollow
    cut wrapped in the same `front_thickness+assembly_gap` translate as
    the case body's own local frame so it lines up correctly against both
    that (built in this local frame) and the legs/skirt (built directly
    in the true global frame the translate maps into). Verified by
    probing a point inside the leg's overlap band, well past the interior
    boundary: empty, where it previously would have been solid leg
    material. Also checked what actually remains at that overlap point —
    exactly a `back_thickness`-thick connecting wall between the leg and
    the case's own hollow boundary, matching the wall thickness
    everywhere else (rather than either the old unwanted thick block or
    a full disconnect). Re-verified floor-flush contact still holds.
28. **I/O bay cutout (items 15, 16, 17) removed entirely — the skirt's own
    recess now serves the same purpose.** With the leg skirt in place
    (item 22) providing a recessed area between the legs for cables to
    exit, the user felt the separate I/O bay pocket in the back panel
    above it was redundant — asked about improving its "big open hole"
    look first, then concluded it wasn't needed at all once the skirt was
    accounted for. Removed the whole cutout (footprint, wedge-tracked
    floor, all `io_bay_*` params) from `rear_shell()`. Since `leg_skirt()`
    depended on `io_bay_w` (for its width) and `io_bay_d` (for its "flush
    with the bay's floor" depth reference), those became standalone
    `skirt_width` (`= case_width - 2*feet_width`, same value as before)
    and `skirt_depth` (`=25`, same default as the old `io_bay_d`) params
    instead — the skirt's actual position and size are unchanged, just no
    longer defined in terms of a feature that no longer exists. The back
    panel is now a plain continuous surface (aside from the vent slats)
    down to where the legs begin.
29. **Attempted a small bevel around the back panel's outer perimeter and
    the legs' back-bottom corner — reverted, not currently in the model.**
    First pass added two separate features: a diagonal clip chamfering the
    legs' back-bottom corner (where the floor clip meets the rear-plane
    clip — verified working via probes), and a `chamfered_tapered_shell()`
    meant to fillet the case body's own outer edges via the same "erode
    every axis by `bevel`, then `minkowski()` back out" trick
    `leg_side_shape()` uses.

    User feedback after seeing it rendered: only the leg's corner read as
    bevelled; the case's own edges didn't, and the leg's corner bevel
    wasn't wanted in the first place ("the back of the leg actually
    shouldn't have a bevel"). Removed the leg's diagonal clip per that
    feedback. Re-investigating the case's own bevel then turned up a real
    bug, not just a subtlety of rendering: probing the same edge location
    at `back_edge_bevel=0.01` vs `5` returned *identical* geometry,
    meaning the parameter wasn't doing anything there — and a wider probe
    found the "bevel" was in fact distorting a large swath of the side
    face (most of the case's height), not a small edge fillet. The
    earlier claim in this log that the erode/regrow round-trip "returns
    flat faces to their exact original position" was checked with too
    coarse a probe (bulk facet dumps that turned out to be picking up
    unrelated geometry — vent slats, ordinary corner-radius curvature —
    rather than the bevel itself) and didn't actually catch this.

    Rather than ship geometry with a known, not-yet-understood defect,
    removed `chamfered_tapered_shell()` entirely and reverted the outer
    rear housing to plain `tapered_shell()` (its pre-item-29 state,
    re-verified manifold and floor-flush). The case's own back panel
    currently has no edge bevel; revisiting this is an open item — likely
    needs the erosion math re-derived (probably the linear
    `d_bottom + slope*b - b` approximation for how far to erode the taper
    doesn't correctly account for the sloped face's normal direction not
    being axis-aligned) and should be checked with a tight, single-point
    probe at the specific edge in question before being reported as
    working, not a bulk-region facet scan.

## Deliberate deviations from the image's numbers

The image's 330×240×95mm spec sheet was the *starting point*, but the
depth and height have since been tuned smaller
(`body_depth_bottom=80`/`body_depth_top=45`/`case_height=189` as of this
writing) based on the user's own hands-on adjustments while iterating in
OpenSCAD — the image's dimensions describe the reference concept, not a
locked target. When guiding future changes, treat the image as the source
of *shape and proportion* (wedge profile, L-leg silhouette, vent
layout/position, rounded corners, front tilt vs. flat back) rather than as
exact millimeter targets — check current values in
`lisa_modern_template.scad` before assuming the spec-sheet numbers still
apply.

## Known open gaps vs. the image

- Apple logo decal — not modeled (decorative, out of scope for a
  printable template).
- FloppyEmu slot — mentioned as optional in the image, not modeled.
- Mouse/keyboard/USB port cutouts and labels — deliberately removed (see
  item 15) and no placeholder cutout remains as of item 28; the leg
  skirt's own recess (see "Legs: seamlessness…" and item 22) is where
  cables are expected to exit once real ports are designed.
- Back panel edge bevel — attempted and reverted (see item 29); the back
  panel's outer perimeter currently meets its sides at a plain
  `corner_radius`-only edge, no additional small chamfer/fillet like the
  front's `front_edge_bevel`.

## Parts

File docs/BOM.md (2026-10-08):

# Bill of Materials

There is a separate parts list for each design:

- [Design A: ESFloppy on back](design_a/BOM.md)
- [Design B: ESFloppy on front](design_b/BOM.md)

See the [README](../README.md#choose-your-design) for a comparison.

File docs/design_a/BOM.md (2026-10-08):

# Design A Bill of Materials: ESFloppy on Back

Parts for the stock design that leaves the LisaFPGA untouched. Build
instructions: [`ASSEMBLY.md`](ASSEMBLY.md). For the front-mounted ESFloppy
version, see [Design B](../design_b/BOM.md).

> **Software requirement:** this build uses an 11.6" 1080p widescreen LCD
> behind a case opening sized for the original 9.7" 4:3 Lisa window. You
> need [the LisaFPGA fork](https://github.com/wottle/LisaFPGA) that offsets the
> displayed image to fit — stock LisaFPGA firmware won't position it
> correctly.

## Printed parts

### Common parts -- `models/print-ready/common/`

| Qty | File |
|---|---|
| 4 | `Lisa_Mini_LCD_Mount_Clips.obj` |
| 1 | `Lisa_Mini_Lisa_Logo_Plate.obj` — Lisa logo badge |
| 1 | `Lisa_Mini_Manufacturer_Blank_Logo_Plate.obj` — plain insert for the bezel's second badge holder; no Apple logo plate is included (see [README](../../README.md) for why) |
| 1 | `Lisa_Mini_Power_Switch.obj` — cap over the LisaFPGA's power switch |
| 1 | `Lisa_Mini_Back_LisaFPGA_SD_Slot_Covers.stl` |

### Design A parts -- `models/print-ready/Lisa_Mini_With_ESFloppy_Screen_And_Buttons_On_Back/`

| Qty | File |
|---|---|
| 1 | `Lisa_Mini_Front.obj` |
| 1 | `Lisa_Mini_Back_LisaFPGA.obj` |
| 1 | `Lisa_Mini_ESFloppy_Shroud.obj` — dresses up the rear ESFloppy screen opening; print in black, no supports needed. Fit isn't perfect and needs a bit of glue to hold — see [ASSEMBLY.md](ASSEMBLY.md) |

## Electronics

| Qty | Item | Notes |
|---|---|---|
| 1 | [LisaFPGA](https://www.tindie.com/products/lisafpga/) board | FPGA re-implementation of the Apple Lisa |
| 1 | [11.6" 1080p widescreen LCD panel](https://www.aliexpress.us/item/3256812306199991.html) | Requires [the LisaFPGA fork](https://github.com/wottle/LisaFPGA) to offset the image within the case's screen opening |
| 1 | [LCD controller board](https://www.aliexpress.us/item/2251832782455852.html) | Drives the LCD panel above |
| 2 | [Buck converter](https://www.amazon.com/dp/B07VVXF7YX) | Steps 12V input down for the LCD/controller and LisaFPGA |
| 1 | [Panel-mount barrel jack, 12V input](https://www.amazon.com/dp/B0DLKN8J7M) | Mounts through the rear shell for power input |
| 1 | [Right-angle USB-C cable, thin/low-profile](https://www.amazon.com/dp/B0FGNB87BX) | LisaFPGA fits tightly in the case — a straight or bulky connector won't clear |
| 1 | [U-shaped HDMI adapter/connector](https://www.amazon.com/dp/B0DB5KKDN2) | Routes HDMI out of the LisaFPGA within the case's tight clearance |
| 1 | [Thin HDMI cable](https://www.amazon.com/dp/B0FB3YDYTT) | LisaFPGA to LCD controller board, low-profile to fit the case |
| 1 | [5V USB-C pigtail cable](https://www.amazon.com/dp/B0GBGLNR52) | Powers the LCD controller board off one of the buck converters |

Links are the specific parts used in the build — equivalents will generally
work, but panel/controller pairing in particular should match (a mismatched
LCD/controller pair won't drive correctly). The LisaFPGA sits in a tight
fit inside the case, so the right-angle USB-C, U-shaped HDMI, and low-profile
HDMI cable aren't just convenience picks — standard straight connectors or
thicker cables may not clear.

Both 5V power runs (buck converter → LisaFPGA, buck converter → LCD
controller) use USB-C connectors rather than permanent wiring. This is
deliberate: it lets the front-mounted parts (LCD + controller board) and
back-mounted parts (LisaFPGA + power) quick-disconnect from each other,
making it much easier to separate the shells for maintenance.

## Hardware

| Qty | Item | Used for |
|---|---|---|
| 4 | M3 x 4mm screws | Secure the LCD mount clips holding the LCD panel in place |
| 4 | M3 x 4mm screws | Secure the LisaFPGA board to the back shell's standoffs |

## Optional

- A few capacitors across the LCD and LisaFPGA power rails, to smooth
  inrush/startup current draw — not required, but helps if you see
  brownout/reset issues at power-on

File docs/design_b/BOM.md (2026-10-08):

# Design B Bill of Materials: ESFloppy on Front

Parts for the design that moves the ESFloppy screen, buttons and lit
power button to the front. It requires soldering to the LisaFPGA. Build
instructions: [`ASSEMBLY.md`](ASSEMBLY.md). For the stock design that
leaves the board untouched, see [Design A](../design_a/BOM.md).

> **Software requirement:** this build uses an 11.6" 1080p widescreen LCD
> behind a case opening sized for the original 9.7" 4:3 Lisa window. You
> need [the LisaFPGA fork](https://github.com/wottle/LisaFPGA) that offsets the
> displayed image to fit — stock LisaFPGA firmware won't position it
> correctly.

## Printed parts

### Common parts -- `models/print-ready/common/`

| Qty | File |
|---|---|
| 4 | `Lisa_Mini_LCD_Mount_Clips.obj` |
| 1 | `Lisa_Mini_Lisa_Logo_Plate.obj` — Lisa logo badge |
| 1 | `Lisa_Mini_Manufacturer_Blank_Logo_Plate.obj` — plain insert for the bezel's second badge holder; no Apple logo plate is included (see [README](../../README.md) for why) |
| 1 | `Lisa_Mini_Power_Switch.obj` — cap over the LisaFPGA's power switch |
| 1 | `Lisa_Mini_Back_LisaFPGA_SD_Slot_Covers.stl` |

### Design B parts -- `models/print-ready/Lisa_Mini_With_ESFloppy_Screen_And_Buttons_On_Front/`

| Qty | File |
|---|---|
| 1 | `Lisa_Mini_Front_With_ESFloppy_Screen.obj` |
| 1 | `Lisa_Mini_Front_With_ESFloppy_Slot_Filler_Black.obj` — print in black |
| 1 | `Lisa_Mini_Back_LisaFPGA_ESFloppy_Moved_To_Front.obj` |
| 1 | `Lisa_Mini_ESFloppy_Screen_Clip.obj` |
| 1 | `Lisa_Mini_ESFloppy_Button_Cap.obj` |
| 3 | `Lisa_Mini_ESFloppy_Button_Inner_qty3.obj` — single part, print 3 copies |
| 3 | `Lisa_Mini_ESFloppy_Button_Outer_qty3.obj` — single part, print 3 copies |
| 1 | `Lisa_Mini_Power-Button.stl` — front-mounted lit power button |

## Design B extra parts

| Qty | Item | Notes |
|---|---|---|
| 3 | [Push buttons](https://a.co/d/0cvuNnPx) | The front ESFloppy buttons |
| 1 | [Master power rocker switch](https://a.co/d/08oj8ZMu) | Added by this design; same switch used in the author's Raspberry Pi build |
| 1 | Header pins and Dupont wires | Extend the ESFloppy buttons and the ESFloppy LCD to the front |
| 1 | Hookup wire | More wire for the new buttons and the power button |
| 1 | LED | For the lit power button; amber or yellow suits the board's 3.3V rail (see [ASSEMBLY.md](ASSEMBLY.md)) |
| 1 | Soldering iron | Required for the board modifications |
| 1 | Optional: [replacement ESFloppy LCD](https://www.aliexpress.us/item/3256809306858810.html) | If you damage the original while removing it. Get the **4-pin** version. The author used the white-text version; a blue-text version is also available |

## Electronics

| Qty | Item | Notes |
|---|---|---|
| 1 | [LisaFPGA](https://www.tindie.com/products/lisafpga/) board | FPGA re-implementation of the Apple Lisa |
| 1 | [11.6" 1080p widescreen LCD panel](https://www.aliexpress.us/item/3256812306199991.html) | Requires [the LisaFPGA fork](https://github.com/wottle/LisaFPGA) to offset the image within the case's screen opening |
| 1 | [LCD controller board](https://www.aliexpress.us/item/2251832782455852.html) | Drives the LCD panel above |
| 2 | [Buck converter](https://www.amazon.com/dp/B07VVXF7YX) | Steps 12V input down for the LCD/controller and LisaFPGA |
| 1 | [Panel-mount barrel jack, 12V input](https://www.amazon.com/dp/B0DLKN8J7M) | Mounts through the rear shell for power input |
| 1 | [Right-angle USB-C cable, thin/low-profile](https://www.amazon.com/dp/B0FGNB87BX) | LisaFPGA fits tightly in the case — a straight or bulky connector won't clear |
| 1 | [U-shaped HDMI adapter/connector](https://www.amazon.com/dp/B0DB5KKDN2) | Routes HDMI out of the LisaFPGA within the case's tight clearance |
| 1 | [Thin HDMI cable](https://www.amazon.com/dp/B0FB3YDYTT) | LisaFPGA to LCD controller board, low-profile to fit the case |
| 1 | [5V USB-C pigtail cable](https://www.amazon.com/dp/B0GBGLNR52) | Powers the LCD controller board off one of the buck converters |

Links are the specific parts used in the build — equivalents will generally
work, but panel/controller pairing in particular should match (a mismatched
LCD/controller pair won't drive correctly). The LisaFPGA sits in a tight
fit inside the case, so the right-angle USB-C, U-shaped HDMI, and low-profile
HDMI cable aren't just convenience picks — standard straight connectors or
thicker cables may not clear.

Both 5V power runs (buck converter → LisaFPGA, buck converter → LCD
controller) use USB-C connectors rather than permanent wiring. This is
deliberate: it lets the front-mounted parts (LCD + controller board) and
back-mounted parts (LisaFPGA + power) quick-disconnect from each other,
making it much easier to separate the shells for maintenance.

## Hardware

| Qty | Item | Used for |
|---|---|---|
| 4 | M3 x 4mm screws | Secure the LCD mount clips holding the LCD panel in place |
| 4 | M3 x 4mm screws | Secure the LisaFPGA board to the back shell's standoffs |

## Optional

- A few capacitors across the LCD and LisaFPGA power rails, to smooth
  inrush/startup current draw — not required, but helps if you see
  brownout/reset issues at power-on

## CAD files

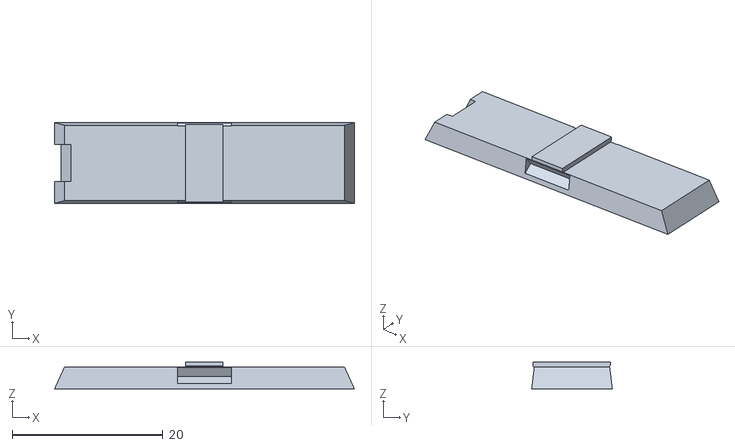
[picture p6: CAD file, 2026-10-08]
models/print-ready/common/Lisa_Mini_Back_LisaFPGA_SD_Slot_Covers.stl
39.8 x 10.7 x 3.57

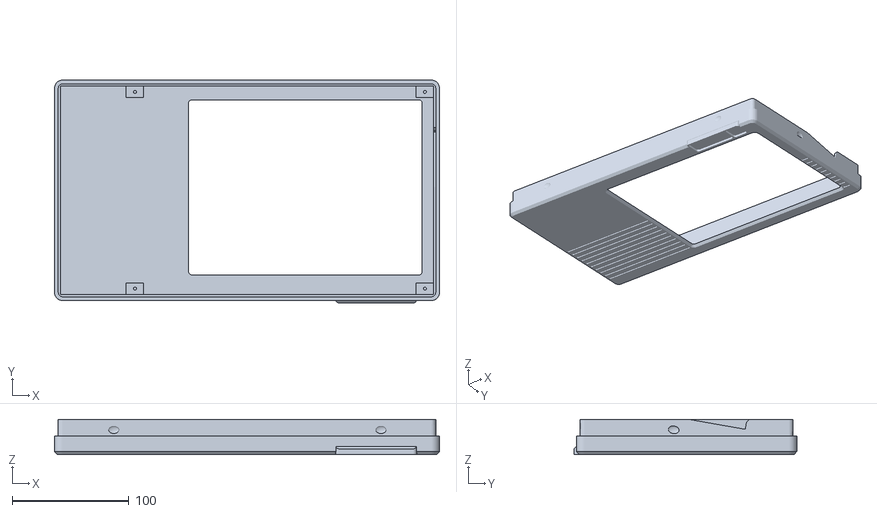
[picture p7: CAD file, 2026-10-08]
models/print-ready/Lisa_Mini_With_ESFloppy_Screen_And_Buttons_On_Back/Lisa_Mini_Front.obj
330.0 x 191.0 x 30.0

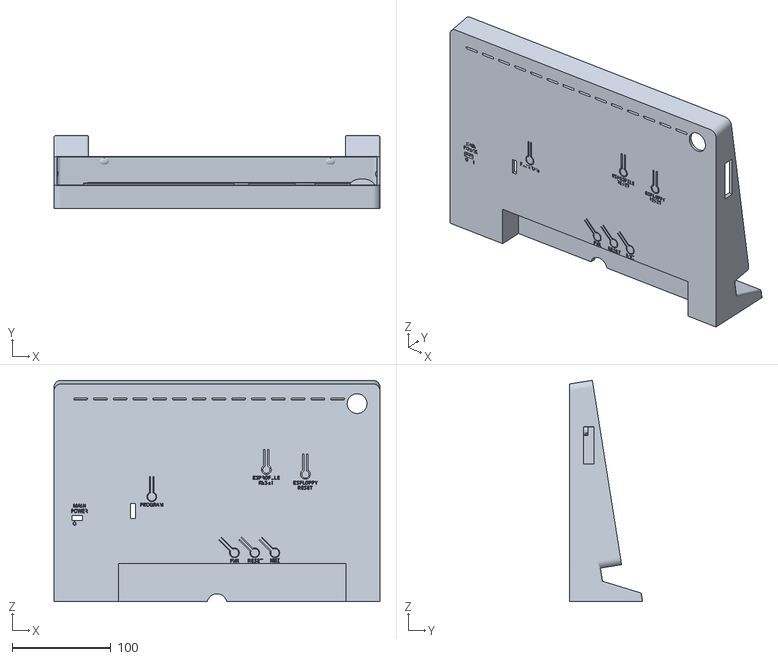
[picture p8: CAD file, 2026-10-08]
models/print-ready/Lisa_Mini_With_ESFloppy_Screen_And_Buttons_On_Front/Lisa_Mini_Back_LisaFPGA_ESFloppy_Moved_To_Front.obj
330.0 x 74.3 x 224.1

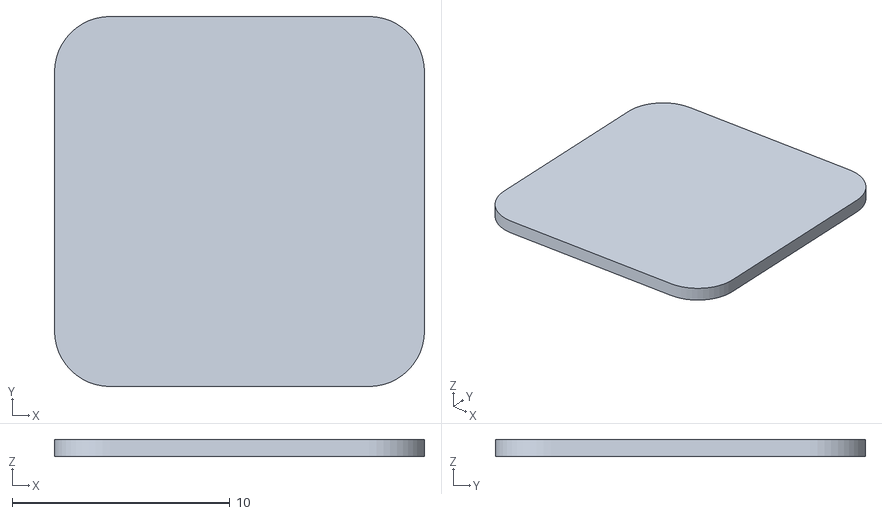
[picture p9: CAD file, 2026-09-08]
models/print-ready/common/Lisa_Mini_Manufacturer_Blank_Logo_Plate.obj
17.0 x 17.0 x 0.8

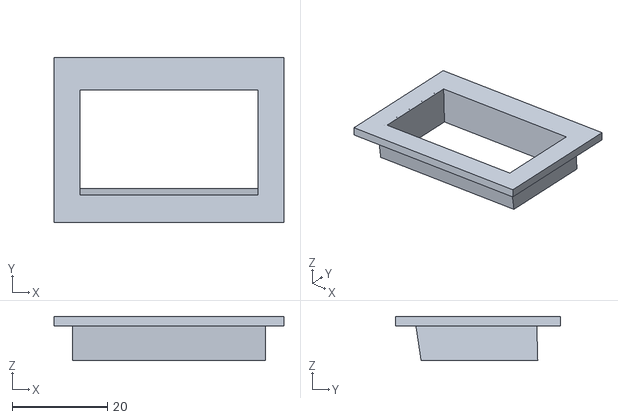
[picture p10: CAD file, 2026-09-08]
models/print-ready/Lisa_Mini_With_ESFloppy_Screen_And_Buttons_On_Back/Lisa_Mini_ESFloppy_Shroud.obj
48.4 x 34.8 x 9.30

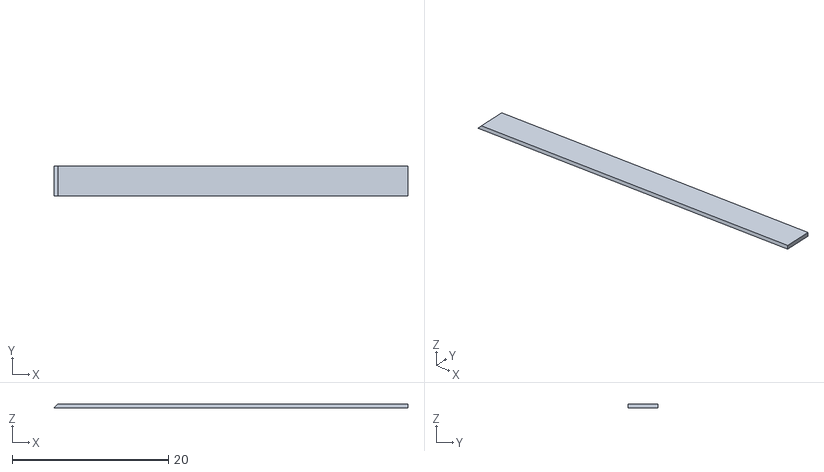
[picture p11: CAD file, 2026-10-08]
models/print-ready/Lisa_Mini_With_ESFloppy_Screen_And_Buttons_On_Front/Lisa_Mini_Front_With_ESFloppy_Slot_Filler_Black.obj
45.3 x 3.80 x 0.5

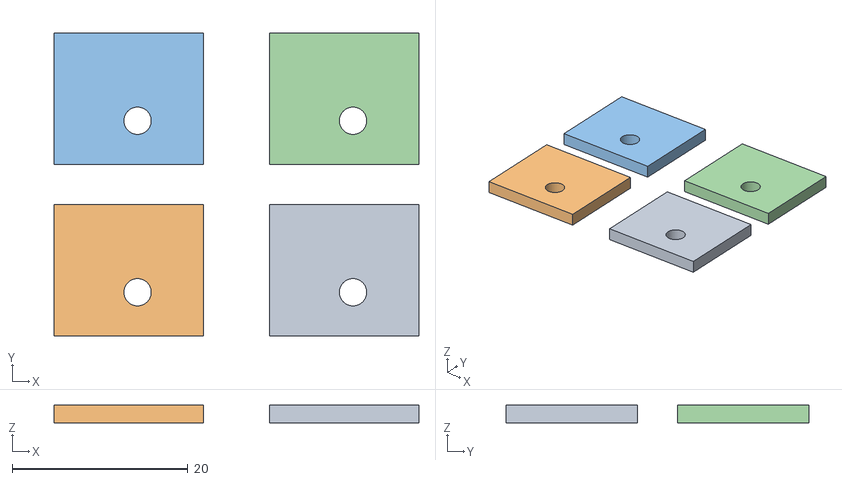
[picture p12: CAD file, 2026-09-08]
models/print-ready/common/Lisa_Mini_LCD_Mount_Clips.obj
41.5 x 34.5 x 2.00
obj_0
obj_1
obj_2
obj_3

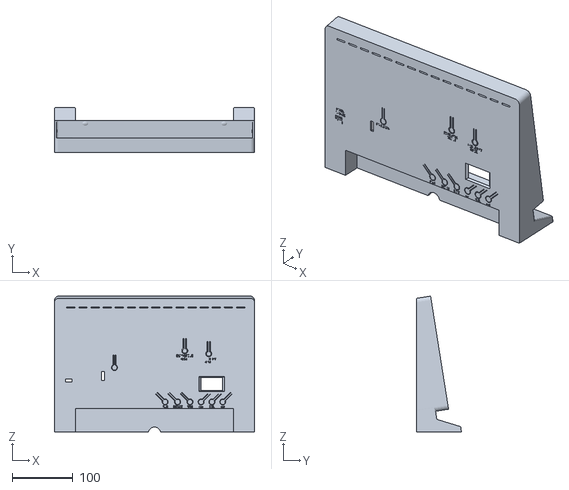
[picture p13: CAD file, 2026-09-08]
models/print-ready/Lisa_Mini_With_ESFloppy_Screen_And_Buttons_On_Back/Lisa_Mini_Back_LisaFPGA.obj
330.0 x 74.3 x 224.1

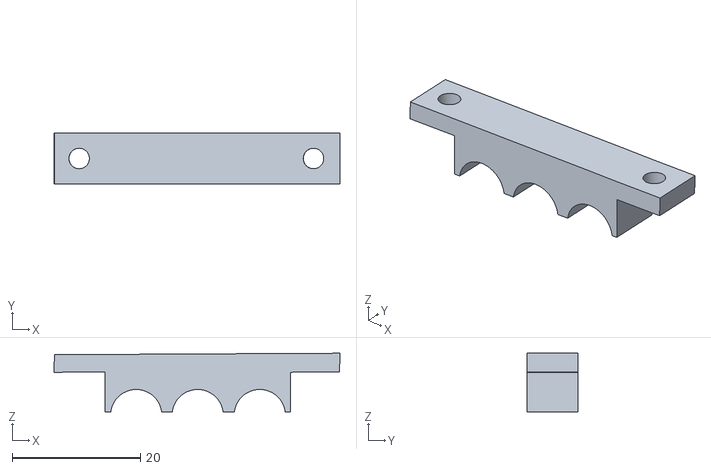
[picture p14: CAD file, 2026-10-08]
models/print-ready/Lisa_Mini_With_ESFloppy_Screen_And_Buttons_On_Front/Lisa_Mini_ESFloppy_Button_Cap.obj
44.7 x 8.00 x 9.15

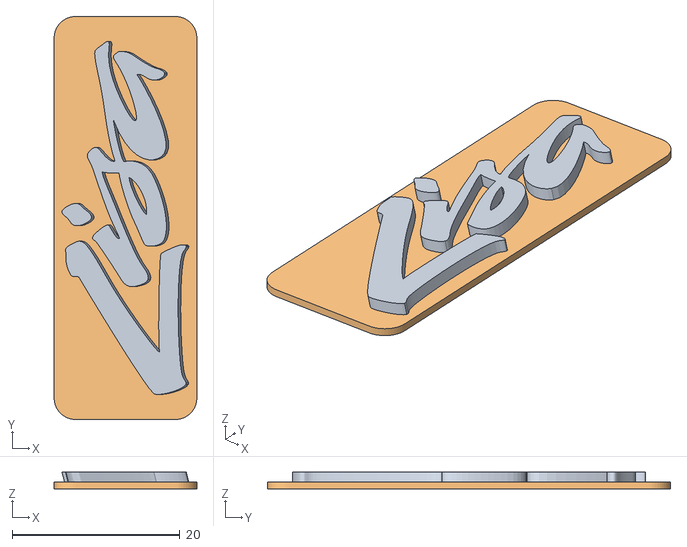
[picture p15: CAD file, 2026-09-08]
models/print-ready/common/Lisa_Mini_Lisa_Logo_Plate.obj
17.0 x 48.0 x 2.00
obj_0
obj_1

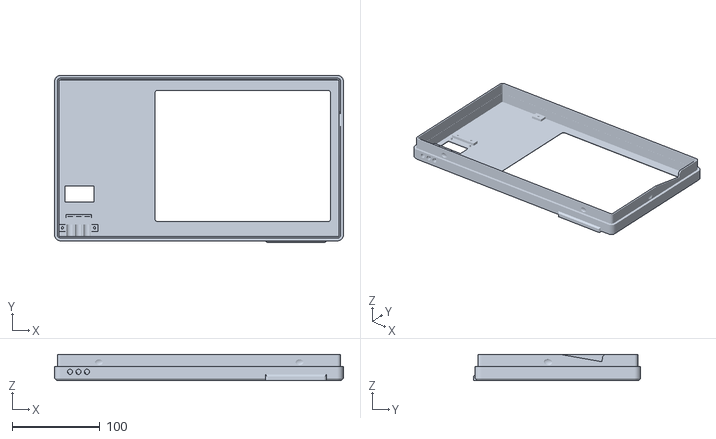
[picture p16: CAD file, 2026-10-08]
models/print-ready/Lisa_Mini_With_ESFloppy_Screen_And_Buttons_On_Front/Lisa_Mini_Front_With_ESFloppy_Screen.obj
330.0 x 191.0 x 30.0

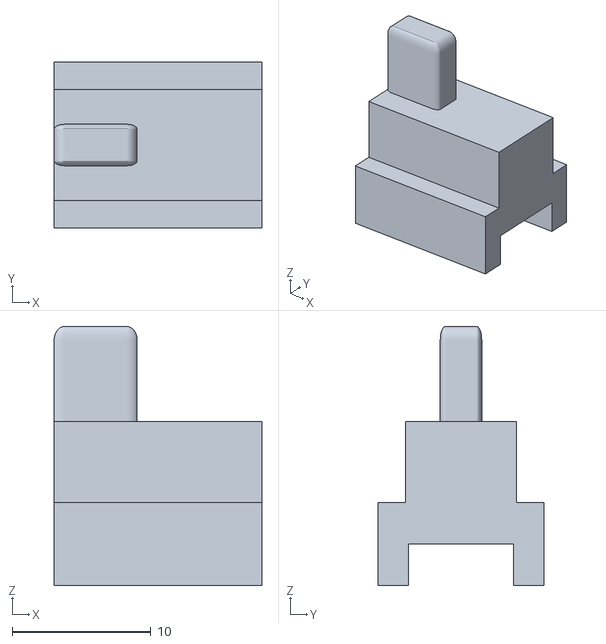
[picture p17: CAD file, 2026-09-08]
models/print-ready/common/Lisa_Mini_Power_Switch.obj
15.0 x 12.0 x 18.7

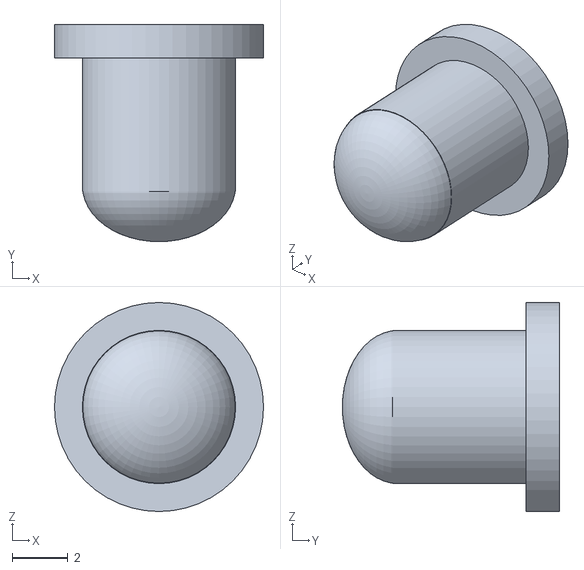
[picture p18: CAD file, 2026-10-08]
models/print-ready/Lisa_Mini_With_ESFloppy_Screen_And_Buttons_On_Front/Lisa_Mini_ESFloppy_Button_Outer_qty3.obj
7.50 x 7.80 x 7.50

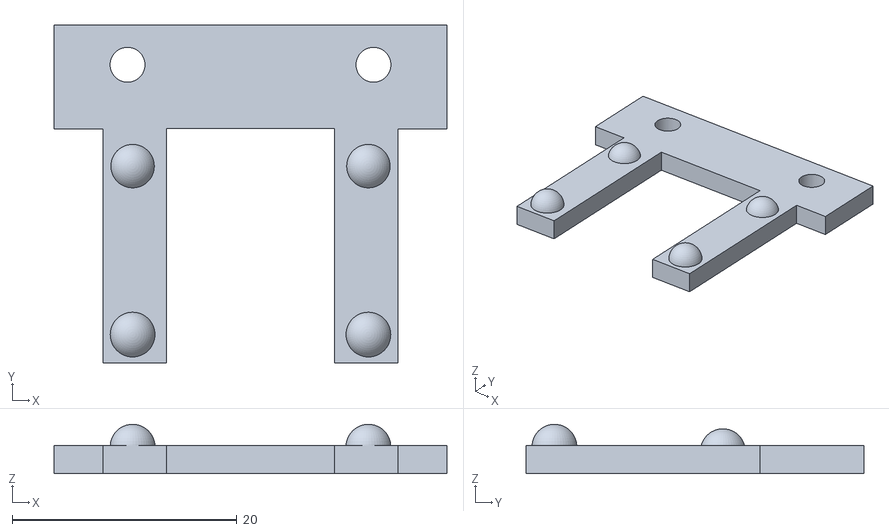
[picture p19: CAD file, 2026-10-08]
models/print-ready/Lisa_Mini_With_ESFloppy_Screen_And_Buttons_On_Front/Lisa_Mini_ESFloppy_Screen_Clip.obj
35.0 x 30.1 x 4.40

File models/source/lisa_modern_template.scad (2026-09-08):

/*
Lisa-inspired modern LCD enclosure
Parametric starter model for OpenSCAD / TinkerCAD

Designed as a starting template for:
- 9.7-inch 4:3 LCD (approx. 197 x 148 mm visible area)
- single PCB behind the display
- printer bed up to about 350 mm wide
- shallow modern enclosure
- narrow left bezel with short vent lines
- wider right-side vent field
- wide Lisa-style feet
- rear recessed label area; ports themselves are not exposed in this template

QUICK START
1. Install OpenSCAD.
2. Open this file.
3. Press F5 for preview.
4. Change "part" below to export individual pieces.
5. Press F6, then File > Export > Export as STL.
6. Import the STL into TinkerCAD.

Important:
This is a concept template, not a production-ready mechanical enclosure.
Measure your exact LCD, PCB, cable plugs, and mounting-hole locations before printing.
*/

// -------------------------
// USER SETTINGS
// -------------------------

part = "front";
// Options:
// "assembly", "front", "back", "lcd_bracket", "pcb_plate"
// (the legs print as part of "back" -- there's no separate foot piece)

$fn = 48;

// Overall body
case_width        = 330;
case_height       = 189;
body_depth_bottom = 70;    // depth at floor level (wedge base)
body_depth_top    = 40;    // depth at top of case (wedge tip)
corner_radius     = 7;

// Shell
front_thickness  = 16;    // how much of the case's total depth belongs to the front piece (see rear_shell()) --
                          // bounded above by interior_depth needing to stay comfortably deeper than cap_depth
back_thickness   = 3.0;
wall_thickness   = 3.0;
assembly_gap     = 0.35;

// Front cap skirt -- lets the front bezel act like a cap that friction-fits
// INSIDE the rear shell's hollow interior (see front_cap_skirt()), instead
// of just butting up against it or wrapping around its outside.
cap_depth        = 14;    // how far the skirt reaches back into the rear shell's interior, past the face plate
cap_wall_t       = 1.8;   // skirt wall thickness
cap_clearance    = 0.2;   // per-side gap between the skirt's outer wall and the rear shell's interior cavity wall

// Screen opening
screen_open_w    = 200;
screen_open_h    = 150;
screen_left      = 115;      // adjacent to the narrow vent side, with room on the other side for the wide grille
screen_bottom    = 22;
screen_corner_r  = 2.5;
screen_bevel     = 2.5;      // chamfer softening the screen opening's front edge, beveling inward toward the LCD

// Front bezel's own outer perimeter edge -- separate from screen_bevel,
// which only softens the screen cutout's edge. 45-degree chamfer (see
// chamfered_prism()): must stay under corner_radius or the corner's
// inset radius would go negative.
front_edge_bevel = 2.5;

// Vent pattern
vent_count       = 10;
vent_slot_h      = 2.0;
vent_depth       = 0.8;  // how far the vent lines cut into the front surface -- decorative, not through-cuts
vent_pitch       = 8.0;
left_vent_w      = 8;                              // narrow, physically on the left as viewed
right_vent_w     = 107;                              // wide, physically on the right as viewed
vent_left_x      = case_width - left_vent_w - 4;   // hugs the model's high-x edge, renders on the left
vent_right_x     = 4.5;                             // near the model's low-x edge, renders on the right
vent_top_y       = screen_bottom + screen_open_h - 3;  // vents start level with the top of the screen

// Feet / stance -- per lisa_design.md, the legs are NOT separate parts
// bolted under the case: each is a left/right edge strip of the case's
// own tapered, tilted outer shell, continued straight down to the floor.
// Built inside body_tilt() (see leg_side_shape()) so the taper/tilt is
// shared with the case above it by construction, guaranteeing a seamless
// join instead of a separately-positioned part that has to be numerically
// matched to the case.
feet_height     = 40;   // visible stance height, floor to the case's own bottom edge
feet_width      = 35;   // width of each leg strip, flush with the case's left/right edges
leg_extra_reach = 15;   // how far past feet_height the leg is built before being clipped flush (see leg_side_shape())

// The leg is solid at this point (a plain block); giving it its L profile
// means cutting away the top-front mass, leaving: a riser (matching the
// display's tilt) at the back, bending partway down to a shallow,
// nearly-horizontal top surface that reaches forward to the foot's front
// tip. See leg_side_shape()'s notch_profile().
leg_riser_depth  = 30;  // thickness of the remaining riser, measured from the back
leg_riser_drop   = 22;  // how far down from the case the riser (display-angle) segment runs before bending
leg_toe_drop     = 18;  // how far further down the bend-to-foot segment runs before reaching the foot's front --
                        // this is the ceiling on how much lower the toe can end up than the knee (see notch_profile()
                        // comment on the riser/foot-slope math): with leg_foot_slope=0 this would be the full
                        // available drop (roughly leg_toe_drop*cos(tilt_angle())); bigger leg_foot_slope spends part
                        // of that ceiling on forward reach instead of drop, so the two need tuning together for a
                        // target toe height, not separately
leg_foot_slope   = 17;  // degrees below horizontal for the foot's top surface (see notch_profile()) -- also trades
                        // off against leg_toe_drop (see above): higher = steeper-looking wedge but less forward reach
leg_rear_extra_reach = 20;  // how far past the case's true depth the leg's back edge is built before being
                            // clipped flush by rear_plane_z() -- same build-deep-then-clip trick as leg_extra_reach/floor
leg_edge_round   = 2;  // fillet radius rounding the leg's exposed (convex) front corners -- knee, toe,
                                    // and the leg's own X-end caps (see leg_side_shape()). Matches corner_radius
                                    // deliberately: the leg's X-end cap fillet is the vertical continuation of the
                                    // case's own corner rounding right above it, so a mismatched radius here reads
                                    // as a visible seam/step at y=leg_overlap where the leg meets the case body.

// Leg skirt -- a thin solid wall filling the gap between the legs below
// the case's own bottom edge (see leg_skirt()), recessed from the true
// exterior surface. Closes off what would otherwise be open air there,
// both to read more like the original Lisa's solid underside and to
// provide a recess for cables to exit (this stood in for, and has now
// replaced, a separate I/O bay cutout in the back panel above it -- see
// lisa_design.md item 28).
skirt_width      = case_width - 2 * feet_width;  // matches the gap between the legs exactly
skirt_depth      = 25;    // how far behind the true exterior surface the skirt sits, before skirt_offset
skirt_thickness  = 6.365;
skirt_offset     = -10;  // shifts the skirt off of "flush with the true exterior surface, skirt_depth back":
                          // positive moves it forward (toward the true exterior surface), negative moves
                          // it backward (deeper into the case, away from the viewer)

// LCD bracket
lcd_overlap      = 4;
lcd_bracket_t    = 3;
lcd_bracket_d    = 8;

// PCB plate
pcb_plate_w      = 310;
pcb_plate_h      = 48;
pcb_plate_t      = 2.8;
pcb_hole_d       = 3.2;
pcb_hole_inset   = 9;

// -------------------------
// HELPER MODULES
// -------------------------

module rounded_2d(w, h, r) {
    offset(r = r)
        offset(delta = -r)
            square([w, h], center = false);
}

module rounded_prism(w, h, d, r) {
    linear_extrude(height = d)
        rounded_2d(w, h, r);
}

module rounded_cut(w, h, d, r) {
    linear_extrude(height = d)
        rounded_2d(w, h, r);
}

// A through-cut like rounded_cut, but with its front edge (z=0) chamfered:
// the opening is widened by `bevel` right at the surface and tapers back
// down to the true w x h size over a depth of `bevel`, softening the
// otherwise sharp edge where the hole meets the face.
module beveled_cut(w, h, d, r, bevel) {
    union() {
        hull() {
            translate([-bevel, -bevel, -0.5])
                rounded_cut(w + 2 * bevel, h + 2 * bevel, 0.01, r + bevel);
            translate([0, 0, bevel])
                rounded_cut(w, h, 0.01, r);
        }
        translate([0, 0, bevel])
            rounded_cut(w, h, d - bevel, r);
    }
}
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

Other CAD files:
models/print-ready/Lisa_Mini_With_ESFloppy_Screen_And_Buttons_On_Front/Lisa_Mini_ESFloppy_Button_Inner_qty3.obj
models/print-ready/Lisa_Mini_With_ESFloppy_Screen_And_Buttons_On_Front/Lisa_Mini_Power-Button.stl

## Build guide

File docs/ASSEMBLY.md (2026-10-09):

# Assembly Instructions

There are two designs. Pick one and follow its guide:

- [Design A: ESFloppy on back](design_a/ASSEMBLY.md) -- leaves the
  LisaFPGA untouched
- [Design B: ESFloppy on front](design_b/ASSEMBLY.md) -- moves the ESFloppy
  screen, buttons and a lit power button to the front; requires soldering
  to the LisaFPGA

An [assembly video](https://youtu.be/3yojjUhr7K4) is also available. It builds Design B, which
includes every step of Design A plus the extra modifications, so it works
for either design.

See the [README](../README.md#choose-your-design) for a comparison.

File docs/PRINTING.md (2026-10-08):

# Printing Notes

## Recommended settings

| Setting | Value |
|---|---|
| Wall thickness | ~2.4mm (2 perimeters at 0.4mm nozzle, or adjust to match) |
| Infill | 15–20% |
| Layer height | 0.2mm for all parts, except the two logo plates (`Lisa_Mini_Lisa_Logo_Plate.obj`, `Lisa_Mini_Manufacturer_Blank_Logo_Plate.obj`) — 0.12mm with ironing enabled, for surface quality |
| Supports | Front and back both need supports (see below) |
| Bed size required | 350mm — the model is 330mm wide |

## Orientation

File locations: shared parts are in `models/print-ready/common/`; the rest
are in the folder for your chosen design (`Lisa_Mini_With_ESFloppy_Screen_And_Buttons_On_Back/` or
`Lisa_Mini_With_ESFloppy_Screen_And_Buttons_On_Front/`).

- `Lisa_Mini_Front.obj` (Design A) — print face
  down
- `Lisa_Mini_Back_LisaFPGA.obj` — print face up
- `Lisa_Mini_LCD_Mount_Clips.obj`, `Lisa_Mini_Lisa_Logo_Plate.obj`,
  `Lisa_Mini_Manufacturer_Blank_Logo_Plate.obj`, `Lisa_Mini_Power_Switch.obj`
  — small parts, orientation is straightforward from their shape
- `Lisa_Mini_ESFloppy_Shroud.obj` (Design A only) — no supports needed; recommended in
  black filament since it's visible on the back of the case

Slicer plating for both shells:

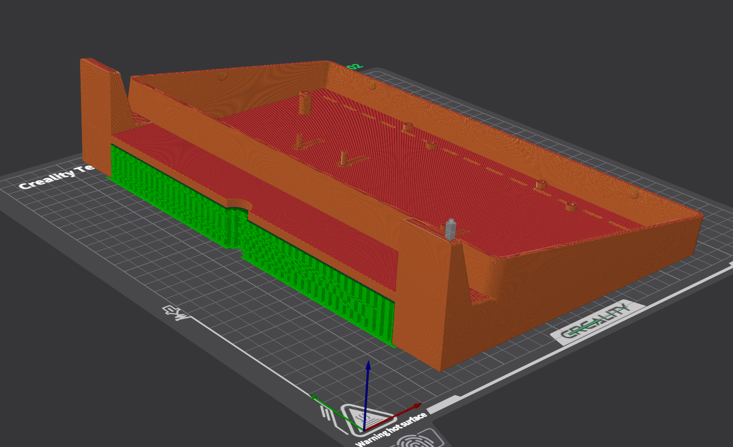
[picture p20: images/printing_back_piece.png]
Back piece print orientation


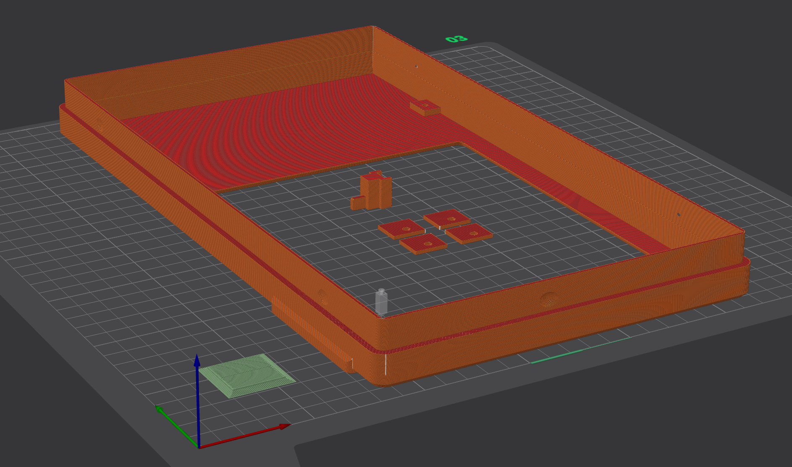
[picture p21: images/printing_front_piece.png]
Front piece and small parts print orientation


The front shell plates together with the LCD mount clips and power switch,
using the open bed space inside the screen cutout.

## Bed size / smaller printers

The model is 330mm wide, so front/back shells need a 350mm print bed to
print in one piece as designed. If your printer's bed is smaller, you can
slice the front/back shells in half and print in two pieces — but the seam
where the halves join will be visible on the finished part. There's
currently no version of this design pre-split for smaller beds.

## Supports

The design was optimized to minimize supports overall, but both shells
currently need them:

- **Back** (`Lisa_Mini_Back_LisaFPGA.obj`) — the skirt between the legs is
  the cause. It's possible to remove that skirt to eliminate most/all of
  the back's support requirement, but that variant hasn't been made yet.
- **Front** (`Lisa_Mini_Front.obj`) —
  needed under the logo plate badge holder area. A PETG support interface
  layer was used there to improve surface quality, though it matters less
  than usual since a logo plate gets inserted into that area anyway,
  covering it.

Print the LCD mount clips (`Lisa_Mini_LCD_Mount_Clips.obj`) and the power
switch (`Lisa_Mini_Power_Switch.obj`) on the same plate as the front
shell — the screen cutout leaves plenty of bed space for these small
parts.

## Material

Printed in [Polar Filament Retro Platinum PLA](https://polarfilament.com/products/retro-platinum-pla-1kg-1-75mm)
— a metallic silver/platinum finish designed for a classic-computing look.
No warping issues on the large front/back shells with this filament.

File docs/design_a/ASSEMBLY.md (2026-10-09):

# Design A Assembly: ESFloppy on Back

This is the stock design. It leaves the LisaFPGA board untouched: the
ESFloppy screen and buttons stay on the board and are reached through the
rear of the case. Parts are listed in [`BOM.md`](BOM.md). Printed parts
come from `models/print-ready/Lisa_Mini_With_ESFloppy_Screen_And_Buttons_On_Back/`
and `models/print-ready/common/`.

An [assembly video](https://youtu.be/3yojjUhr7K4) is available. It builds Design B, which is a
superset of these steps: everything here is shown, plus the ESFloppy and
power button modifications that Design A skips (the ESFloppy shroud and the
power button cutout are Design A only).

Looking for the version that moves the ESFloppy screen, buttons and power
button to the front? See [Design B](../design_b/ASSEMBLY.md).

The LisaFPGA has two different power controls, which this guide keeps
separate:
- The **power switch** turns the whole device on and off. It is covered by
  the printed power switch cap (`Lisa_Mini_Power_Switch.obj`).
- The **Lisa Power button** emulates the power button on the front of the
  original Lisa. Here it is reached through a button cutout on the rear case.

## Before you start

- Confirm you have all parts from [`BOM.md`](BOM.md)
- Test-fit the LCD panel and LisaFPGA board against the printed shells
  before final assembly
- Clean up any stringing/support marks around the vent lines and screen
  opening
- **Flash [the LisaFPGA fork](https://github.com/wottle/LisaFPGA) before
  assembling the case.** It adds the image offset this case needs, plus
  USB host improvements (USB hub support for keyboards and mice) and
  persistent settings. Clone the fork and run `./program_board.sh` from
  the clone, with the board plugged into your computer over a full USB-C
  power+data cable and its power switch on. If your computer asks whether
  to allow the board's USB hub, approve it, then unplug and reconnect the
  board before running the script. Reflashing erases saved settings, so
  re-apply them afterward. See the fork's
  [README](https://github.com/wottle/LisaFPGA#about-this-fork-lisa-mini)
  for details. Once assembled, the LisaFPGA's USB-C port only
  has the low-profile power cable plugged in (no data), so you lose the
  ability to flash new software. To update later, remove the 4 screws
  holding the LisaFPGA to the back shell, unplug the low-profile USB-C
  power cable, and plug in a full USB-C power+data cable to reflash it.

## Steps

### Front assembly

1. **Mount the LCD**
   - Seat the LCD panel into the front bezel, pushed all the way to the
     left side
   - Set a `Lisa_Mini_LCD_Mount_Clips.obj` clip above each of the 4
     mounting holes and screw it down with an M3x4mm screw to hold the
     LCD in place
   - Stick the LCD controller board to the back of the LCD panel with
     double-sided tape, and connect the LCD's ribbon cable and small
     2-pin power connector to it

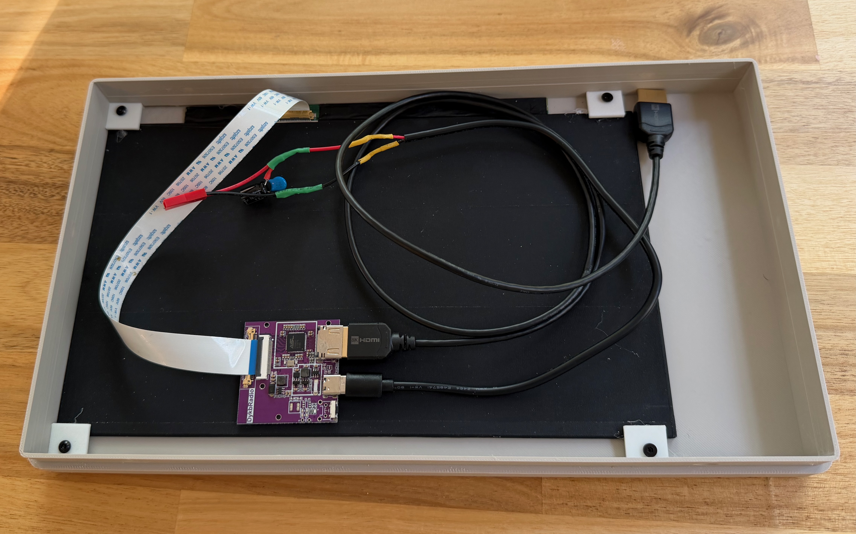
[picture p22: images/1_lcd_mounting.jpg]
LCD and controller board mounted in the front shell
   

2. **Attach the logo plates**
   - Press-fit `Lisa_Mini_Lisa_Logo_Plate.obj` into the bezel's Lisa logo
     plate holder — no glue needed. If it's too tight to press-fit, scale
     the plate down to 99% and reprint
   - Press-fit `Lisa_Mini_Manufacturer_Blank_Logo_Plate.obj` into the
     bezel's second holder the same way — this repo ships it blank rather
     than an Apple logo (see the README for why); swap in your own part
     there if you want a logo

### Back assembly

3. **Install the power input and buck converters**
   - Mount the 12V panel-mount barrel jack into the rear shell
   - Mount the two buck converters along the top edge of the rear shell
   - Wire the barrel jack's 12V output, splitting it into two leads — one
     to each buck converter's input
   - Set each buck converter's output to 5V before connecting anything
     to it. With the 12V input connected and nothing on the outputs,
     measure each converter's output with a multimeter and turn its
     adjustment screw until it reads 5.0V. Check both converters
     individually, and only then connect them to the LisaFPGA or the LCD
     controller

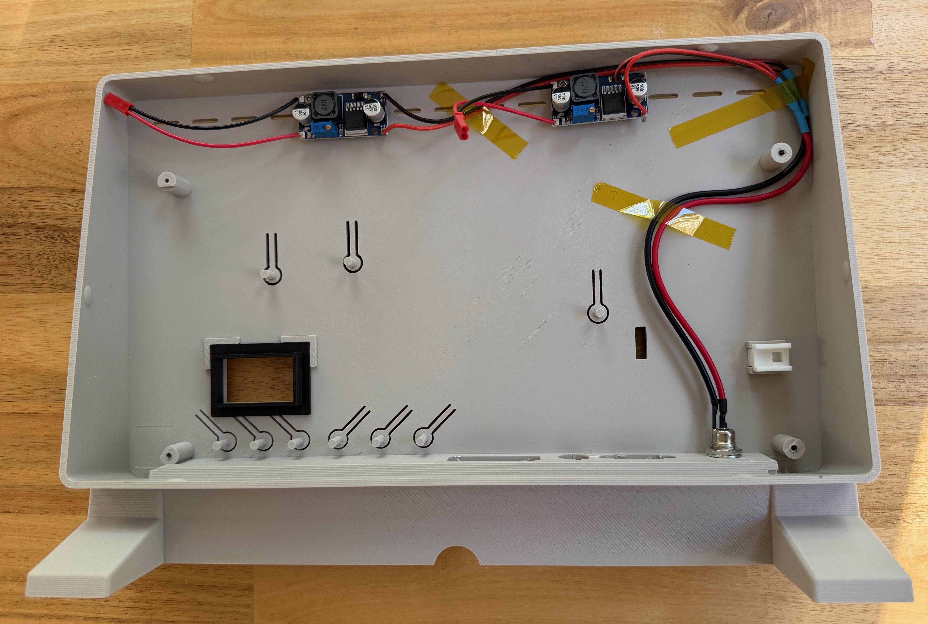
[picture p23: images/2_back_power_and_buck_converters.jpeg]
Back shell with barrel jack and buck converters wired
   

4. **Install the ESFloppy shroud**
   - Fit `Lisa_Mini_ESFloppy_Shroud.obj` into the rear ESFloppy screen
     opening — it dresses up that opening, which currently sits well below
     the back surface
   - Double-check orientation before gluing: the shroud should angle
     toward the top edge of the case
   - The press-fit alone may not hold it — a bit of glue is recommended.
     Use hot glue if you want to be able to remove it later, or superglue
     for a permanent mount. Hot glue is the safer choice for now: the
     current shroud's fit isn't perfect (it exposes a bit too much of the
     area below the ESFloppy LCD), so an improved version may replace it
     without needing to reprint the back shell

5. **Install the power switch cap**
   - Before installing the LisaFPGA board, snap `Lisa_Mini_Power_Switch.obj`
     into its mounting point in the rear shell — the photo below shows its
     orientation. Do this now: once the LisaFPGA board is installed in the
     next step, it covers this area and the switch cap can no longer be
     placed.

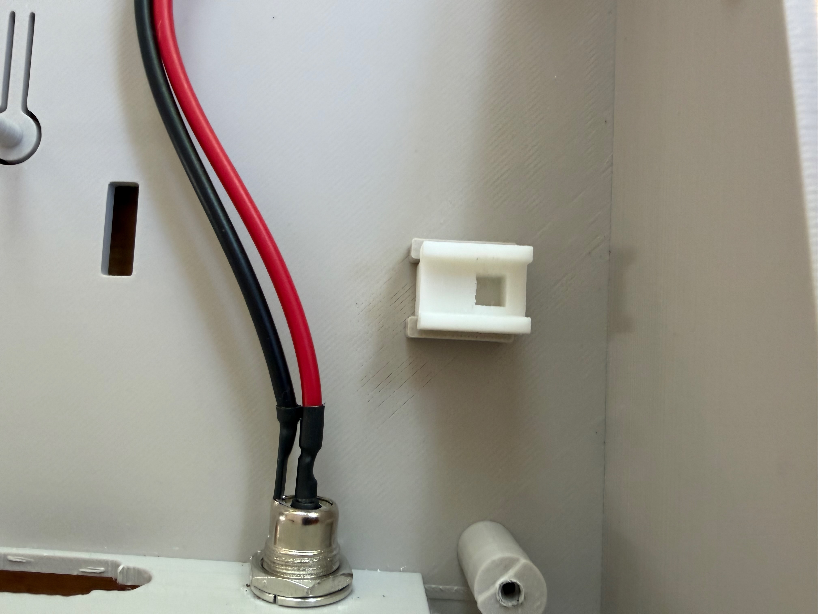
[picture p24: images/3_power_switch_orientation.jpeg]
Power switch cap orientation before installing the LisaFPGA board
   

6. **Install the LisaFPGA board**
   - Before mounting the board, plug the low-profile right-angle USB-C
     cable and the U-shaped HDMI adapter into the LisaFPGA's own ports.
     Do this first — the case's tight clearance around the board makes
     both connectors difficult or impossible to attach once it's screwed
     down
   - Mount the LisaFPGA board into the rear shell
     (`Lisa_Mini_Back_LisaFPGA.obj`) and secure it to the standoffs with 4
     M3x4mm screws — this also covers up the barrel jack wiring
     underneath, and seats the board's onboard switch under the power
     switch cap from step 5
   - Connect the buck converters' 5V outputs to the LisaFPGA board's power
     input and, optionally, an inrush capacitor at the LisaFPGA's power
     connector

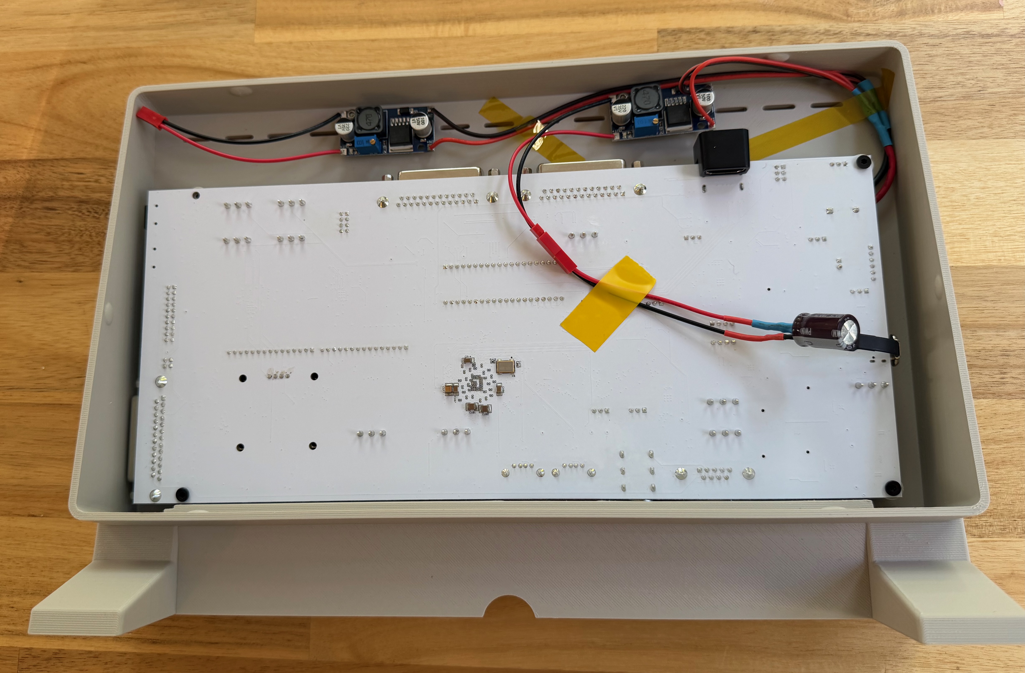
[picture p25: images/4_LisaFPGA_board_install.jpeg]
LisaFPGA board installed and screwed to standoffs
   

### Connect and close

7. **Wire it up**
   - Connect the second buck converter's 5V output to the LCD controller
     board via a USB-C connector rather than a permanent connection
   - Connect the LisaFPGA's U-shaped HDMI adapter (installed in step 6) to
     the LCD controller board with the thin HDMI cable

   These connections use USB-C connectors rather than soldered/permanent
   wiring, deliberately — it lets the front-mounted parts (LCD + controller
   board) and back-mounted parts (LisaFPGA + power) quick-disconnect from
   each other, making it much easier to separate the shells for
   maintenance.

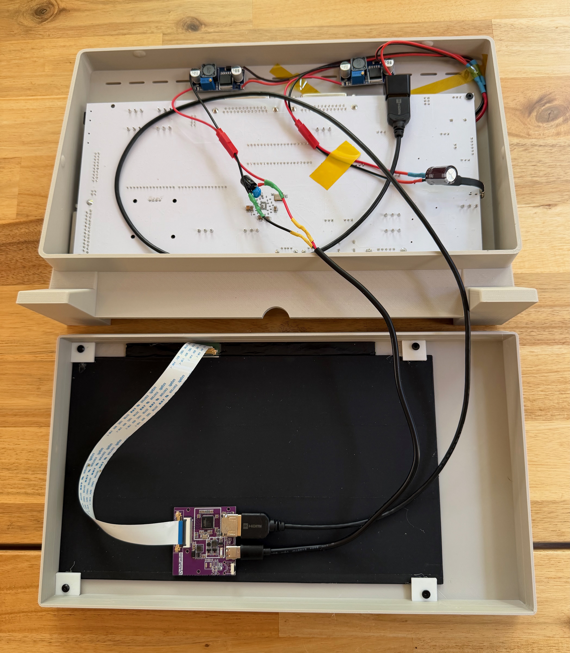
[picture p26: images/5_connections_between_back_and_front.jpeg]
HDMI and 5V power connections between the back and front shells
   

8. **Join front and back shells**
   - The BOM's 8 M3x4mm screws are all accounted for elsewhere (4 for the
     LCD mount clips in step 1, 4 for the LisaFPGA standoffs in step 6) —
     the shells themselves simply press together
   - Small bumps on the back shell align with matching indentations on
     the front shell to help hold the press fit in place

9. **Final check**
   - Power on and verify display output before fully closing up the case
   - Plug a USB keyboard and mouse (directly or through a hub) into the
     LisaFPGA and confirm both respond

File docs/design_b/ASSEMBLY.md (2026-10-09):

# Design B Assembly: ESFloppy on Front

This design moves the ESFloppy screen and buttons, and a lit Lisa Power
button, to the front of the case. It needs soldering to the LisaFPGA board:
wires to the ESFloppy buttons and the Lisa Power button, and removing the
board's own power LED (LED5) to wire a front-mounted one. Parts are listed
in [`BOM.md`](BOM.md). Printed parts come from
`models/print-ready/Lisa_Mini_With_ESFloppy_Screen_And_Buttons_On_Front/` and
`models/print-ready/common/`.

Watch the [assembly video](https://youtu.be/3yojjUhr7K4) for this build.

Prefer to leave the board untouched? See
[Design A](../design_a/ASSEMBLY.md).

The LisaFPGA has two different power controls, which this guide keeps
separate:
- The **power switch** turns the whole device on and off. It is covered by
  the printed power switch cap (`Lisa_Mini_Power_Switch.obj`).
- The **Lisa Power button** emulates the power button on the front of the
  original Lisa. Here it moves to a lit button on the front, so the
  board's own LED is removed and replaced with one in the button.

## Before you start

- Confirm you have all parts from [`BOM.md`](BOM.md)
- Test-fit the LCD panel and LisaFPGA board against the printed shells
  before final assembly
- Clean up any stringing/support marks around the vent lines and screen
  opening
- **Flash [the LisaFPGA fork](https://github.com/wottle/LisaFPGA) before
  assembling the case.** It adds the image offset this case needs, plus
  USB host improvements (USB hub support for keyboards and mice) and
  persistent settings. Clone the fork and run `./program_board.sh` from
  the clone, with the board plugged into your computer over a full USB-C
  power+data cable and its power switch on. If your computer asks whether
  to allow the board's USB hub, approve it, then unplug and reconnect the
  board before running the script. Reflashing erases saved settings, so
  re-apply them afterward. See the fork's
  [README](https://github.com/wottle/LisaFPGA#about-this-fork-lisa-mini)
  for details. Once assembled, the LisaFPGA's USB-C port only
  has the low-profile power cable plugged in (no data), so you lose the
  ability to flash new software. To update later, remove the 4 screws
  holding the LisaFPGA to the back shell, unplug the low-profile USB-C
  power cable, and plug in a full USB-C power+data cable to reflash it.

## Steps

### Front shell

1. **Mount the LCD**
   - Seat the LCD panel into the front bezel, pushed all the way to the
     left side
   - Set a `Lisa_Mini_LCD_Mount_Clips.obj` clip above each of the 4
     mounting holes and screw it down with an M3x4mm screw to hold the
     LCD in place
   - Stick the LCD controller board to the back of the LCD panel with
     double-sided tape, and connect the LCD's ribbon cable and small
     2-pin power connector to it

   LCD and controller board mounted in the front shell

   Note: the front piece in this photo is the Design A front, so it's
   missing the ESFloppy button assembly and the ESFloppy LCD cut-out that
   the Design B front has. The LCD mounts the same way.

2. **Attach the logo plates**
   - Press-fit `Lisa_Mini_Lisa_Logo_Plate.obj` into the bezel's Lisa logo
     plate holder — no glue needed. If it's too tight to press-fit, scale
     the plate down to 99% and reprint
   - Press-fit `Lisa_Mini_Manufacturer_Blank_Logo_Plate.obj` into the
     bezel's second holder the same way — this repo ships it blank rather
     than an Apple logo (see the README for why); swap in your own part
     there if you want a logo

### Modify the LisaFPGA

3. **Move the ESFloppy LCD to the front**
   - Desolder the ESFloppy LCD's pins and remove the LCD. This takes a fair
     amount of heat and can damage the LCD; a replacement 4-pin LCD is
     listed in the BOM
   - Solder header pins to the back of the LCD, and to the LisaFPGA's
     ESFloppy LCD pads, then extend the connection with Dupont wires.
     Match pin 1 to pin 1, and double-check SDA/SCK, power and ground
     against the schematic: a miswired screen just stays black

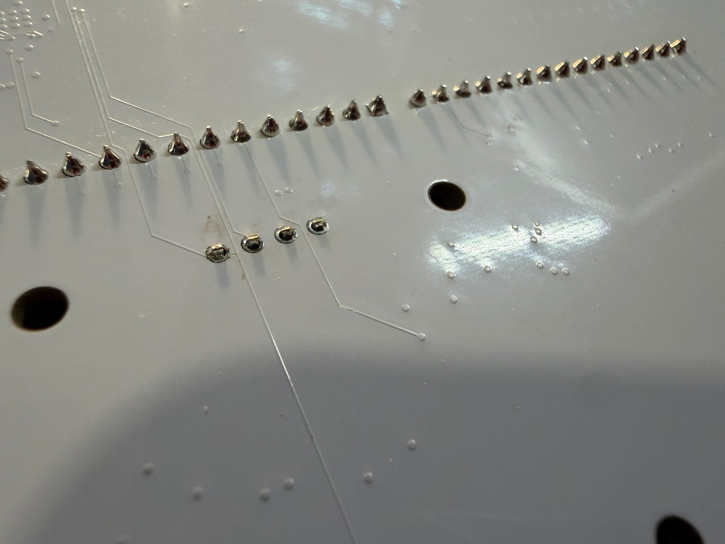
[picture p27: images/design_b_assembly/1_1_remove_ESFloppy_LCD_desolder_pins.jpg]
Desoldering the ESFloppy LCD pins
   

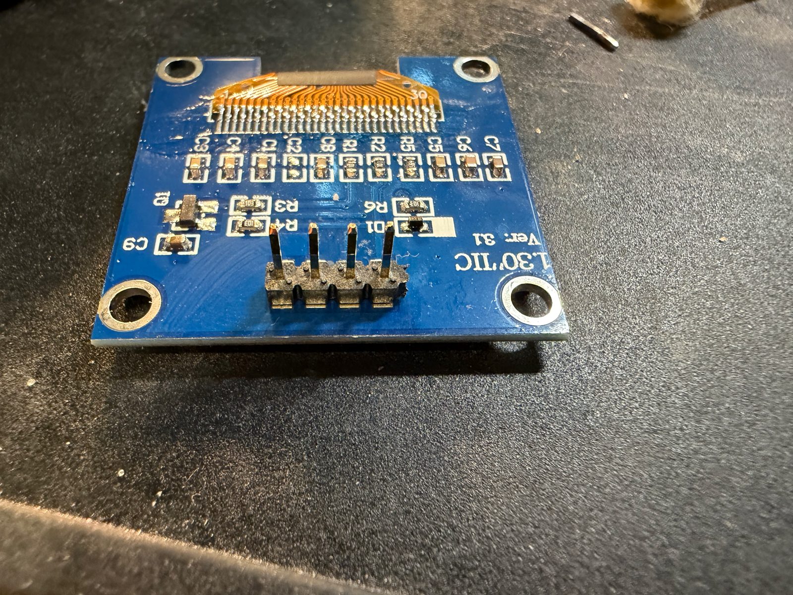
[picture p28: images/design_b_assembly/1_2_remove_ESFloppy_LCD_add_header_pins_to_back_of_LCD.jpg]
Header pins on the back of the LCD
   

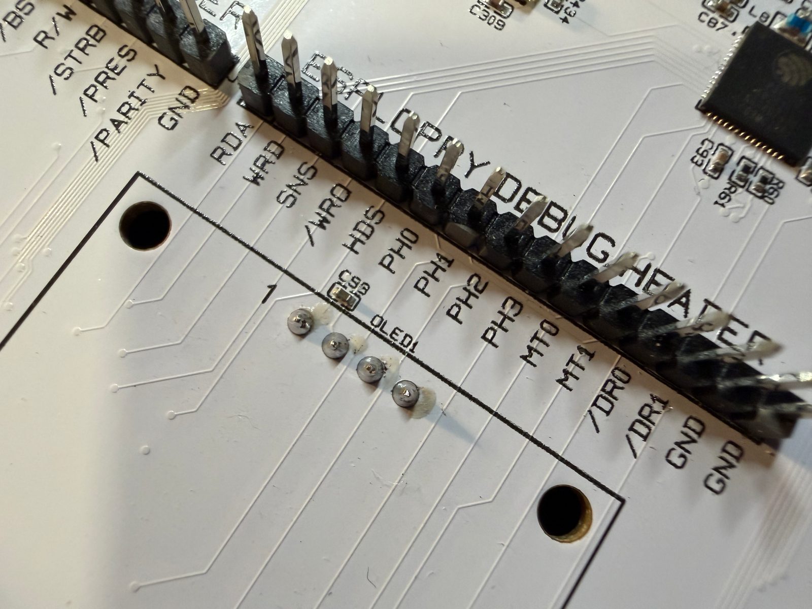
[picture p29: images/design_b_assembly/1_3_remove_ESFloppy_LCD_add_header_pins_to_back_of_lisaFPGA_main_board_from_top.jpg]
Header pins on the LisaFPGA, from the top
   

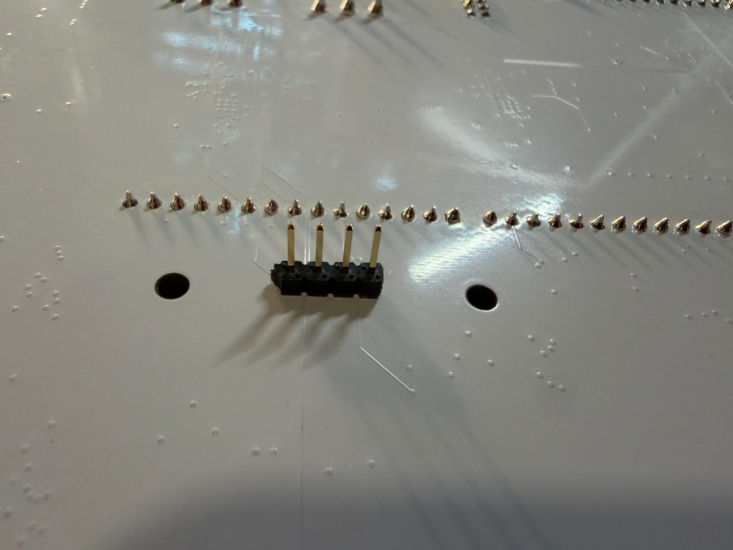
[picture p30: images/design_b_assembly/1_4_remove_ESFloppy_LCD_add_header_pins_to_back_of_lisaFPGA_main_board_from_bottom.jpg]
Header pins on the LisaFPGA, from the bottom
   

4. **Wire the buttons and the power LED**
   - Solder a wire to two legs of each of the ESFloppy LEFT, SEL and RIGHT
     buttons and of the LISA POWER button (6 wires for the ESFloppy
     buttons, plus 2 for the power button)
   - LED5's positive (+) pad is the left one when the board is oriented
     with its silkscreen text the right way up, as in the photos below.
     LEDs only light one way round
   - Remove LED5 and solder two wires to its pads, giving 4 wires for the
     lit power button in total. Label or color-code the wire on the
     left (+) pad so you can tell it from the right (-) one later

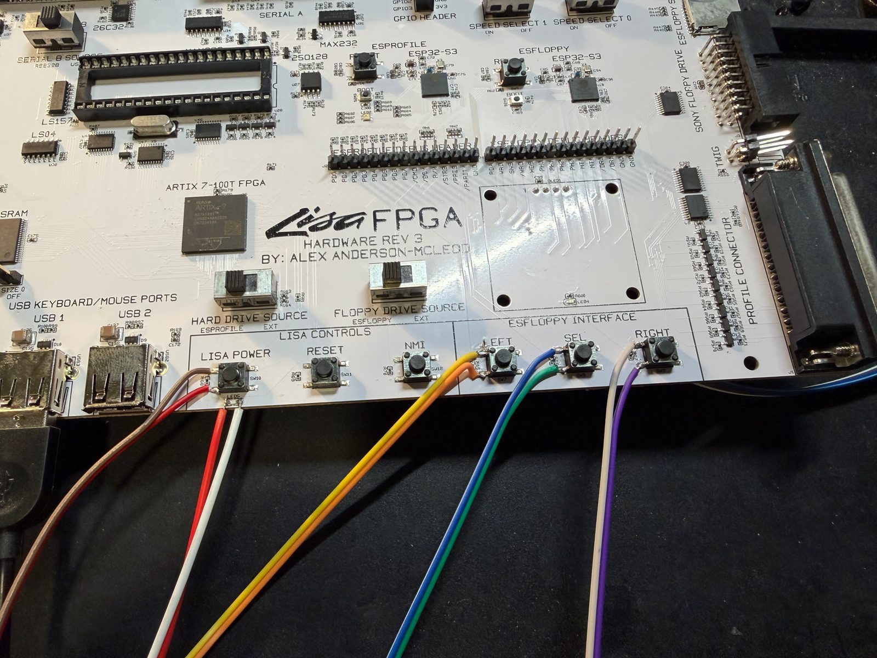
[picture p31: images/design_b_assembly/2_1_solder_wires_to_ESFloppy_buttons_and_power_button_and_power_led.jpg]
Wires soldered to the ESFloppy buttons, power button and power LED pads
   

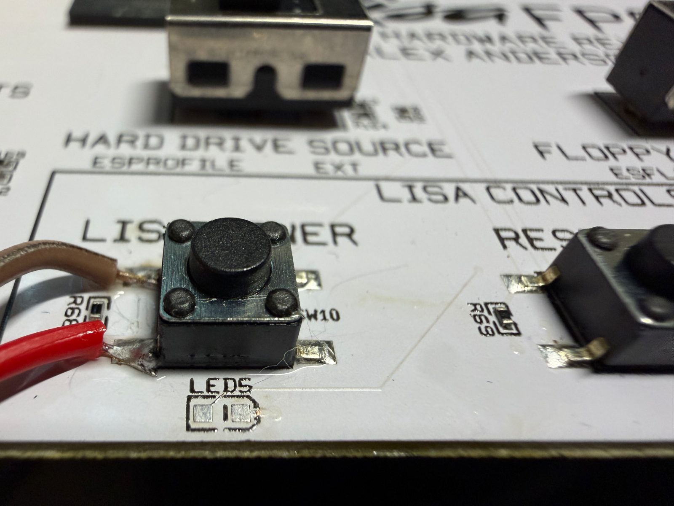
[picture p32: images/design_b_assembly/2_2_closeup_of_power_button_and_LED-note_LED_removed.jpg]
Closeup of the power button and LED pads, with the LED removed
   

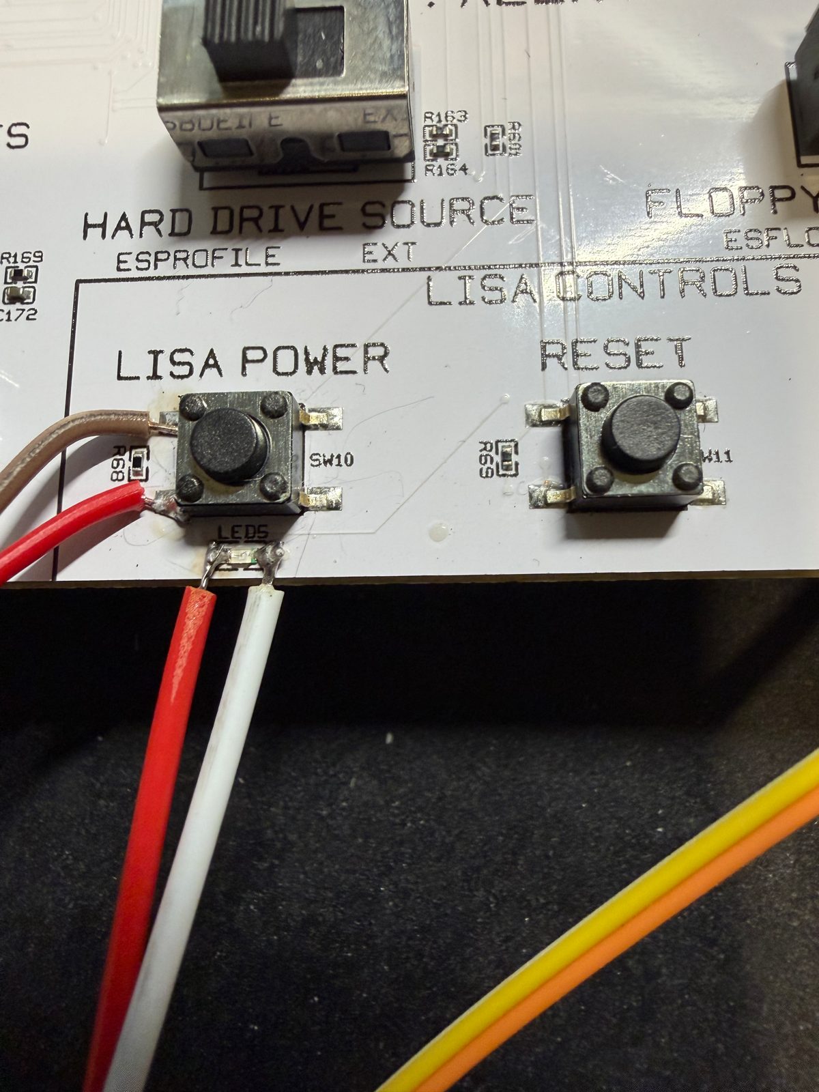
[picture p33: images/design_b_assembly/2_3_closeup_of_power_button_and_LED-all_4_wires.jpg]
Closeup of the power button and LED with all 4 wires
   

   The board's LED current is limited by a fixed resistor on a 3.3V rail,
   so use a low forward-voltage LED: a warm white LED (about 3V) was far
   too dim, whereas amber or yellow (about 2V) is the better fit.

### Buttons and power button

5. **Assemble the buttons and clip in the LCD**
   - Fit the outer button parts (`Lisa_Mini_ESFloppy_Button_Outer_qty3.obj`),
     and seat the push buttons' legs in the button holders
   - Add the inner button pieces (`Lisa_Mini_ESFloppy_Button_Inner_qty3.obj`)
   - Secure the ESFloppy LCD with `Lisa_Mini_ESFloppy_Screen_Clip.obj`
   - Tape the LCD controller board in place

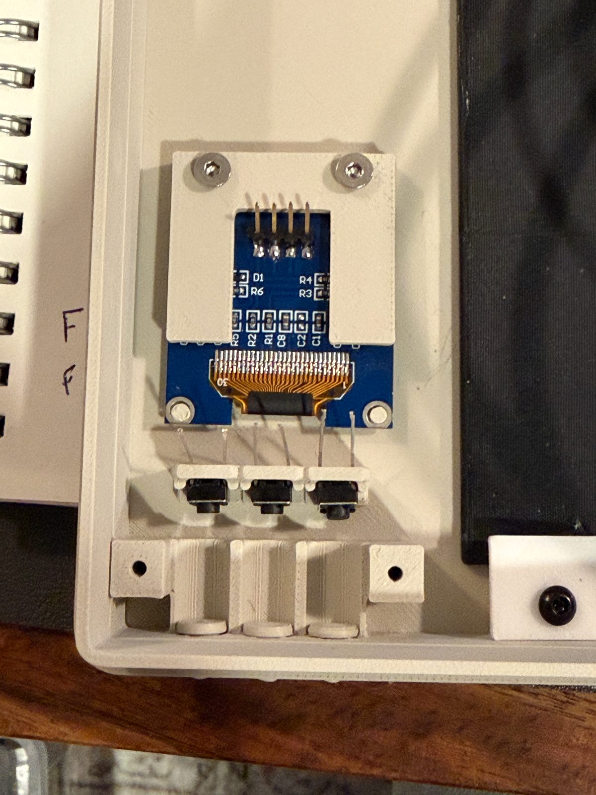
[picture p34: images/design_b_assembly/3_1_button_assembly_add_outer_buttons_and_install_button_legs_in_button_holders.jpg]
Outer buttons installed, with the legs in the button holders
   

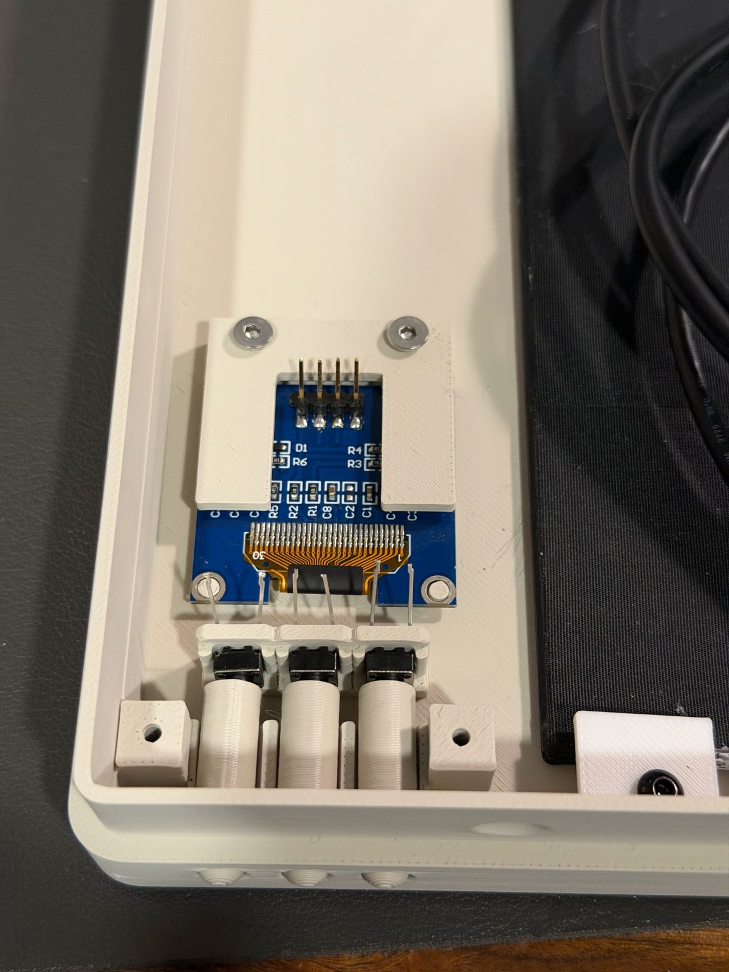
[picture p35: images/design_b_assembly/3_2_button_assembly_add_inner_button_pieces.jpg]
Inner button pieces added
   

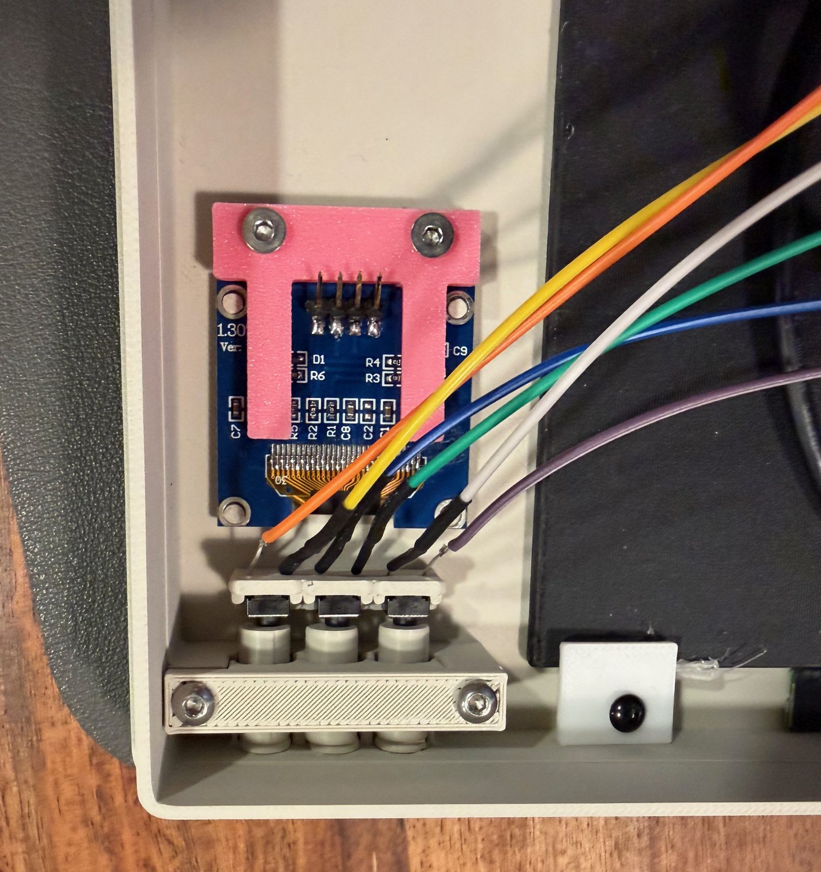
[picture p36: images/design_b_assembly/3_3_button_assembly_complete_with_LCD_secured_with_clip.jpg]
Button assembly complete, with the LCD secured by its clip
   

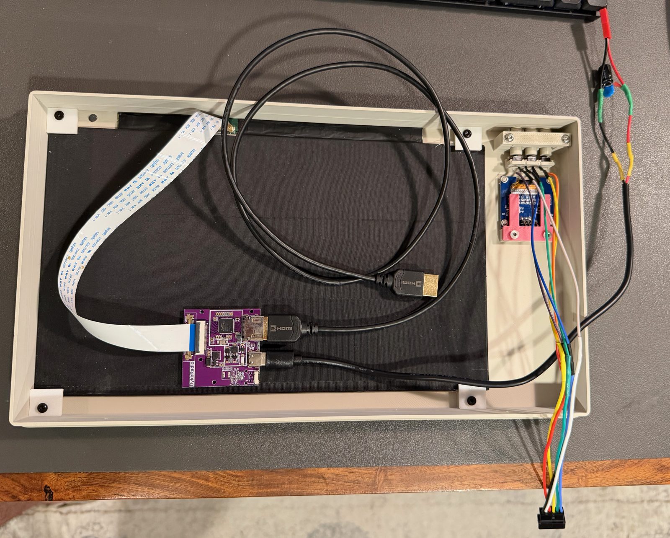
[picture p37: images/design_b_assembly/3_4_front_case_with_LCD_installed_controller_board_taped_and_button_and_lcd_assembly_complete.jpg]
Front case with the LCD installed, controller board taped, and buttons and LCD assembled
   

6. **Wire the lit power button**
   - Wire the 4 wires to the lit power button's switch and LED
     (`Lisa_Mini_Power-Button.stl`). Glue the LED in place first
   - Note the LED's positive (+) leg: the longer leg is usually positive,
     and the flat edge on the LED's rim marks the negative side. Label or
     color-code the wire you solder to the positive leg. It must be
     connected to the positive wire from the LisaFPGA board's LED5 pad
     (step 10), or the LED won't light
   - Fish the 4 wires through the power switch opening

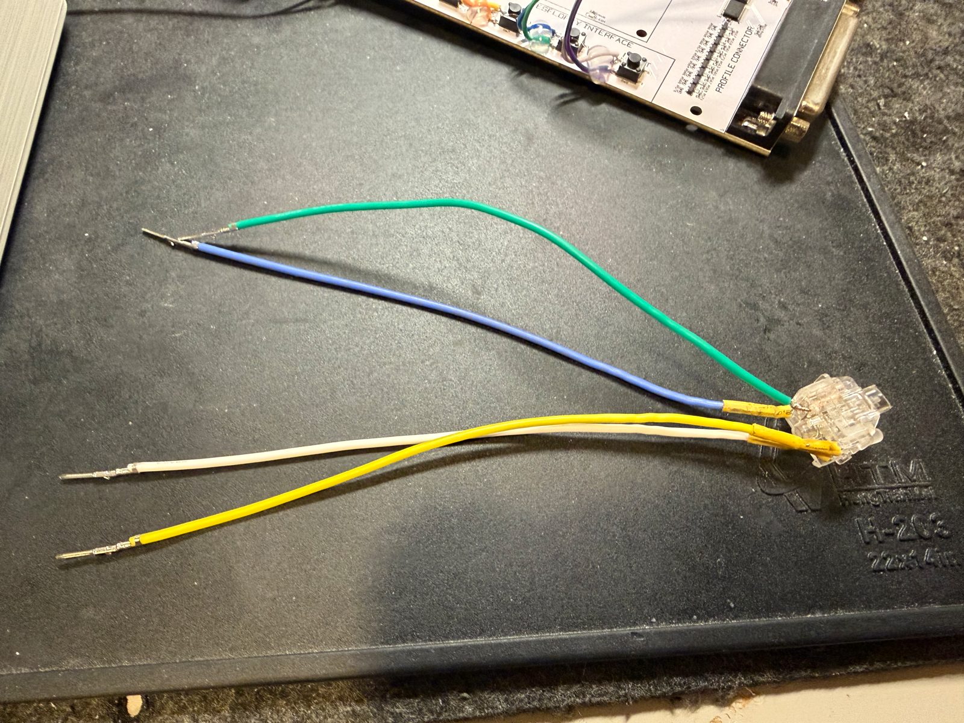
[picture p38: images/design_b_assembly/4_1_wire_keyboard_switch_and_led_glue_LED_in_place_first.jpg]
Wiring the switch and LED
   

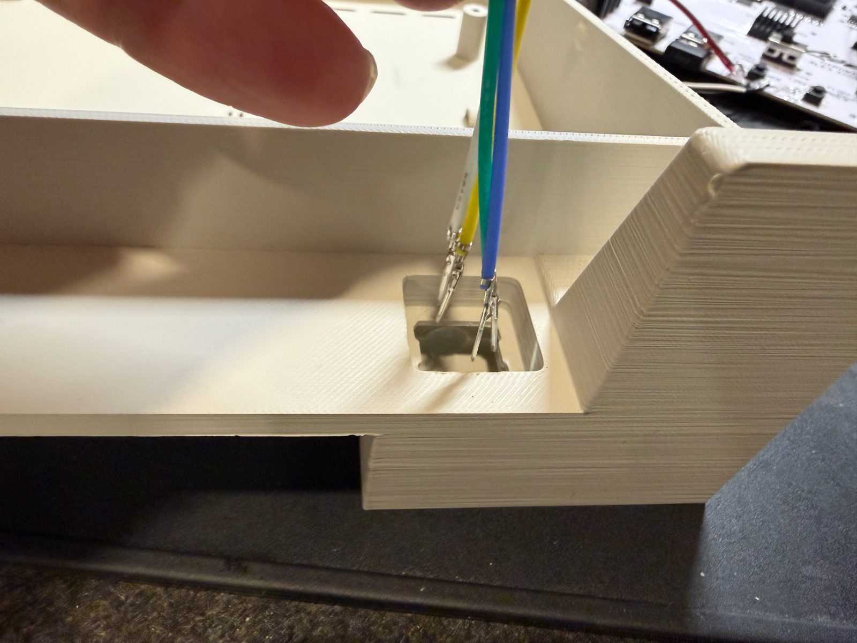
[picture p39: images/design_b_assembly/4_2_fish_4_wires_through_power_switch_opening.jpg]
Fishing the 4 wires through the power switch opening
   

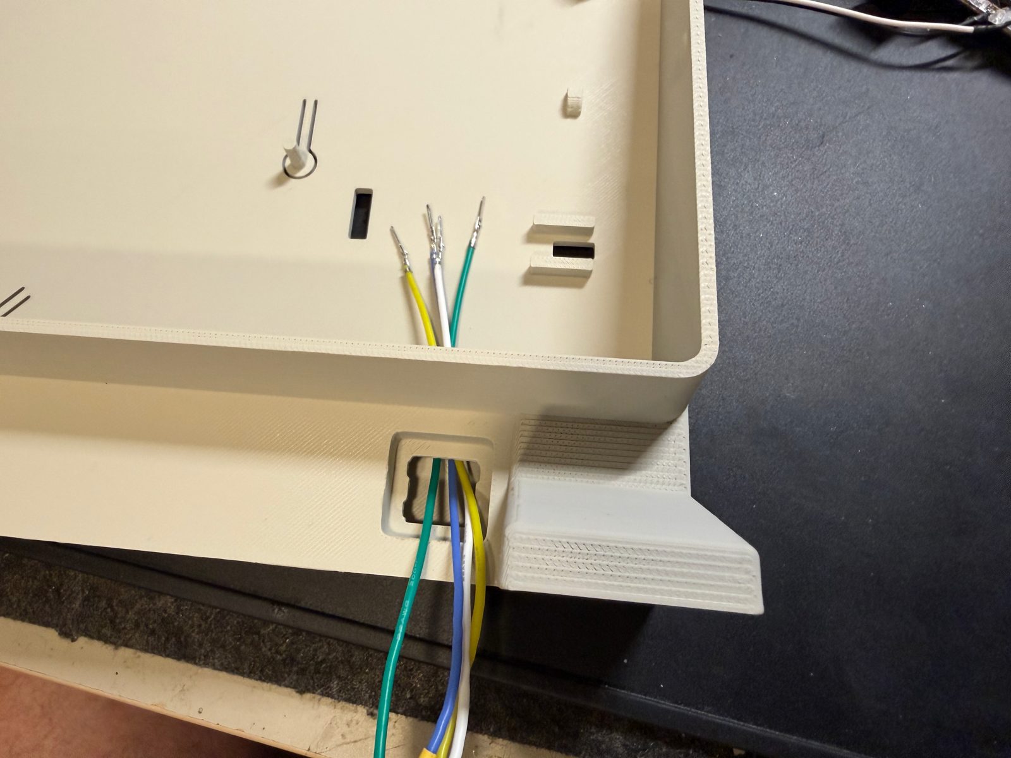
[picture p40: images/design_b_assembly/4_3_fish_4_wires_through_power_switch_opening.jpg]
Fishing the 4 wires through the power switch opening, second view
   

7. **Bundle the wires**
   - Bundle the button and LED wires and pull them up toward the other side
     of the main board

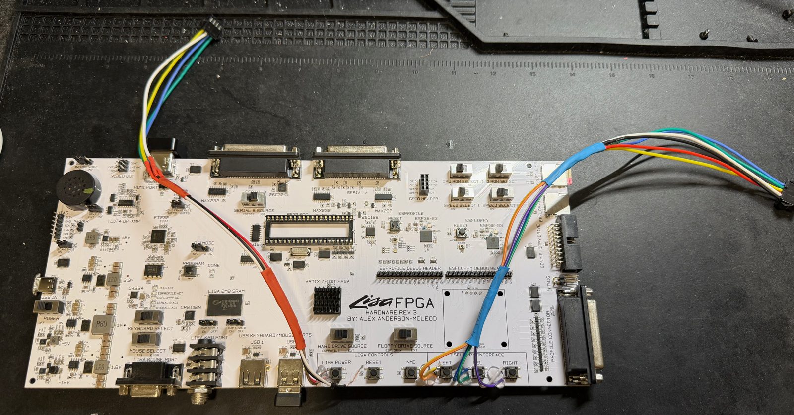
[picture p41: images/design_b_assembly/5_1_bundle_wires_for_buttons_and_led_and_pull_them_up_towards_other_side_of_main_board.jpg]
Bundled button and LED wires
   

### Back assembly

8. **Prepare the back case**
   - Snap `Lisa_Mini_Power_Switch.obj` (the power switch cap) into its
     mounting point in the rear shell, before the LisaFPGA goes in. It's
     the white cap at the upper left of the photo below. The board covers
     this area afterward, so the cap can't be added later
   - Connect the 12V barrel jack to the master power rocker switch, and
     from the switch to the buck converters
   - Set each buck converter's output to 5V before connecting anything
     to it. With the 12V input connected and nothing on the outputs,
     measure each converter's output with a multimeter and turn its
     adjustment screw until it reads 5.0V. Check both converters
     individually, and only then connect them to the LisaFPGA or the LCD
     controller

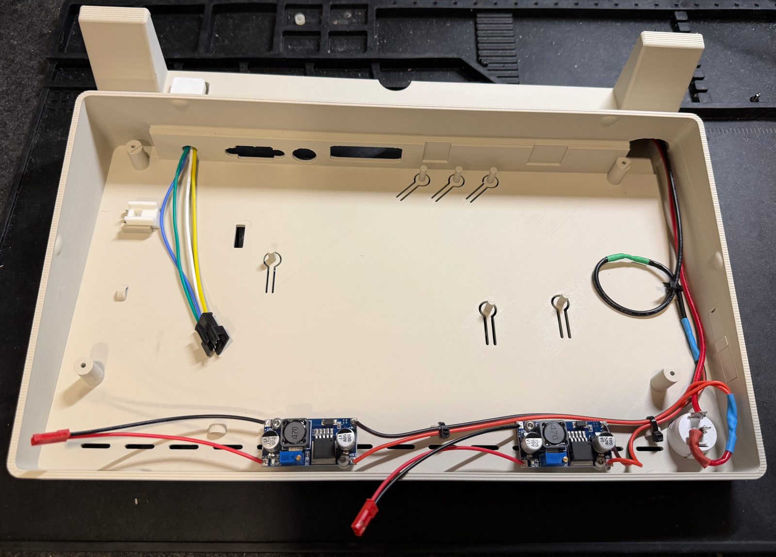
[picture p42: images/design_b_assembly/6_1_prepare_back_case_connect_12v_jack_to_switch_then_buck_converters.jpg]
Back case with the 12V jack, master switch and buck converters
   

9. **Install the LisaFPGA**
   - Before mounting the board, plug the low-profile right-angle USB-C
     cable and the U-shaped HDMI adapter into the LisaFPGA's own ports.
     Do this first: the case's tight clearance around the board makes
     both connectors difficult or impossible to attach once it's screwed
     down
   - Mount the LisaFPGA into the rear shell
     (`Lisa_Mini_Back_LisaFPGA_ESFloppy_Moved_To_Front.obj`) and secure it
     to the standoffs with 4 M3x4mm screws, making sure the power switch
     cap aligns with the switch on the board
   - Pull the button and LED wires out the top, avoiding any buttons
   - Connect the buck converters' 5V outputs to the LisaFPGA board's power
     input and, optionally, an inrush capacitor at the LisaFPGA's power
     connector

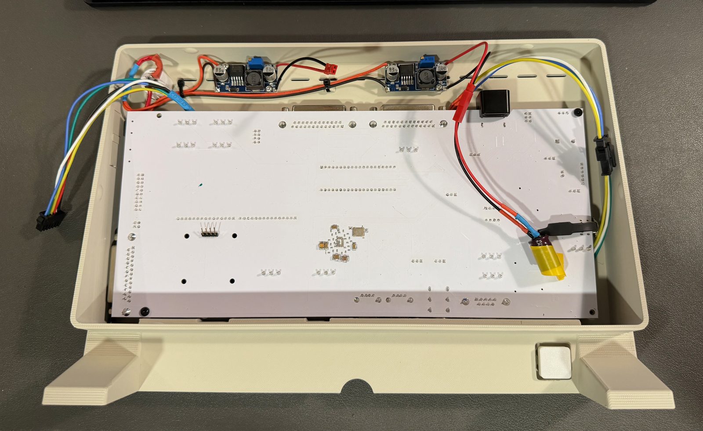
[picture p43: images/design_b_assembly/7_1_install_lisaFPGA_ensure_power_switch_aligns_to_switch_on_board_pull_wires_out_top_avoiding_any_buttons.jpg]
LisaFPGA installed with the power switch aligned
   

10. **Connect the lit power button**
   - Connect the 4 wires from the lit power button to the 4 wires coming
     from the LisaFPGA board. Connect the LED's positive (+) wire to the
     wire from LED5's left (+) pad, and the negative to
     the negative. The two switch wires can go either way round

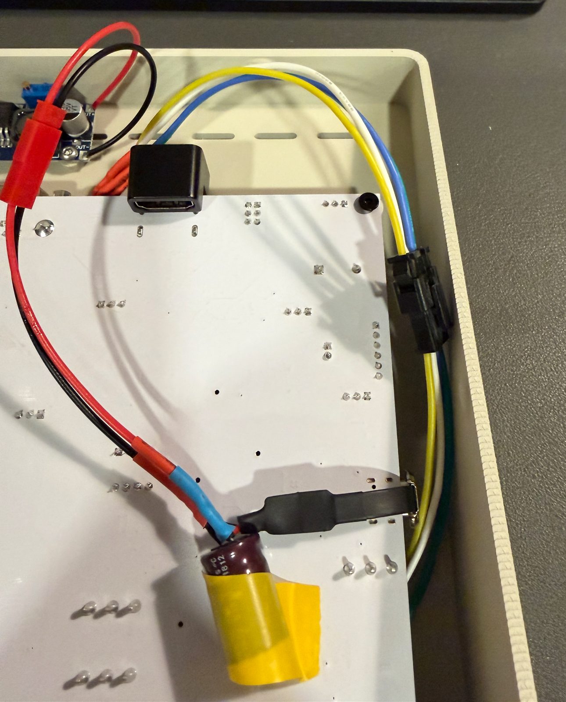
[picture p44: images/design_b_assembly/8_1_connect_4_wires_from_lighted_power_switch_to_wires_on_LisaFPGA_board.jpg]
Connecting the lit power button's wires to the LisaFPGA board's wires
   

11. **Install the SD card slot cover**
   - Take `Lisa_Mini_Back_LisaFPGA_SD_Slot_Covers.stl`, align it with the
     SD card opening, and press it gently into place

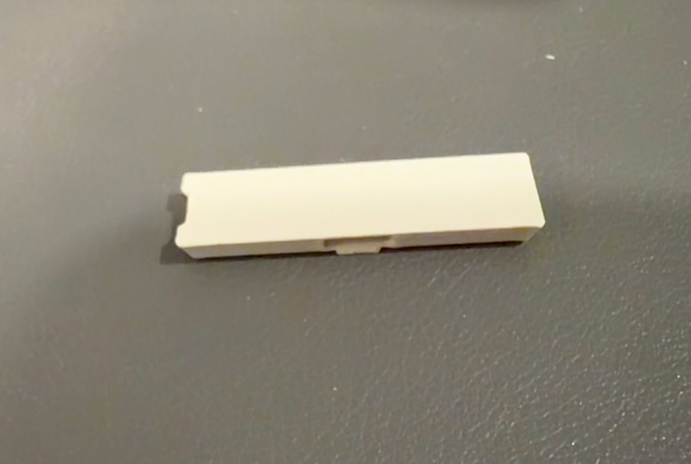
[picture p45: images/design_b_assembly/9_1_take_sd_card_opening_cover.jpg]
SD card opening cover
   

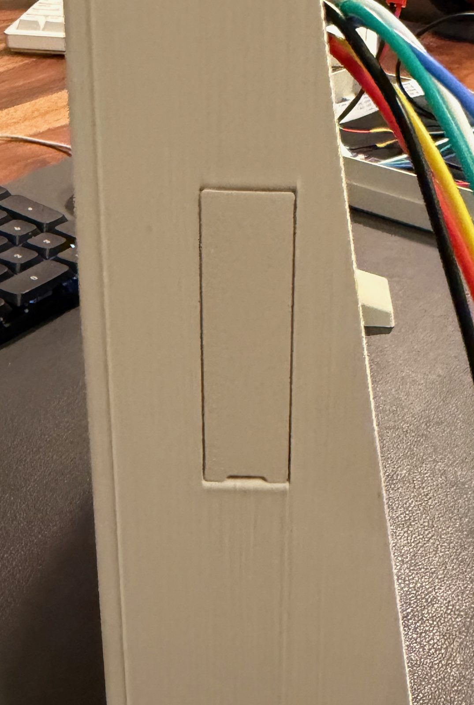
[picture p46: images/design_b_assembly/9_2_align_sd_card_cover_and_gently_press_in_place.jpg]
Aligning the cover and pressing it into place
   

### Connect and close

12. **Connect the front to the back**
   - Connect the ESFloppy LCD, the HDMI and power to the LCD controller
     board, and the 6 wires for the ESFloppy buttons

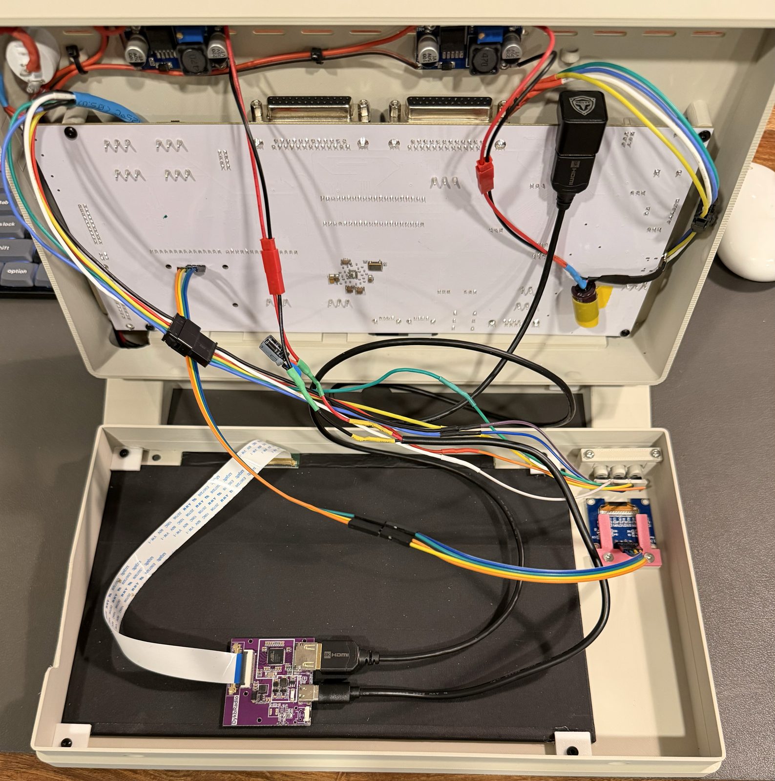
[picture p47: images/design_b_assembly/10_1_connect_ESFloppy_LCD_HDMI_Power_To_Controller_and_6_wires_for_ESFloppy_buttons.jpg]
ESFloppy LCD, HDMI, power and button wires connected between the front and back
   

13. **Close the case**
   - Tuck in the wires and snap the front piece into the back piece

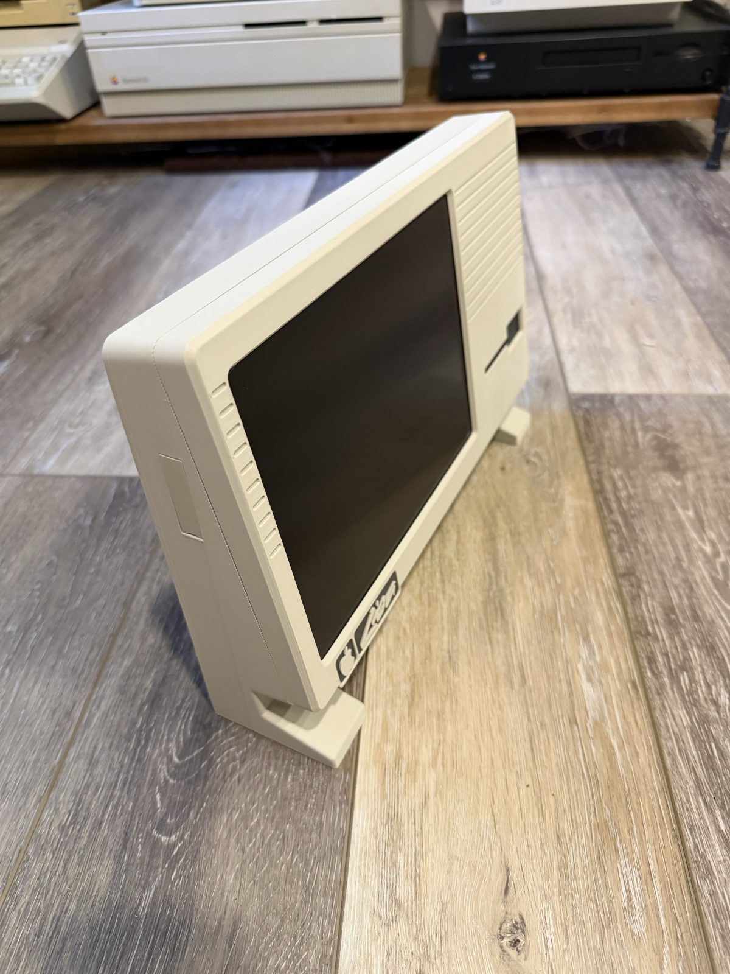
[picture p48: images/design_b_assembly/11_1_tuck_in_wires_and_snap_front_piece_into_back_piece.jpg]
Tucking in the wires and snapping the front onto the back
   

14. **Final check**
   - Power on and verify display output before fully closing up the case
   - Plug a USB keyboard and mouse (directly or through a hub) into the
     LisaFPGA and confirm both respond

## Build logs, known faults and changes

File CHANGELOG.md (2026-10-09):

# Changelog

## Unreleased

- Initial public repo scaffold: front/back shells, LCD mount clips, logo
  plate, and power switch bezel as print-ready OBJ files
- Documented full BOM (LCD, LCD controller, buck converters, barrel jack,
  screws, cabling)
- Documented bed size requirement (350mm), print orientation, and back
  shell's support requirement
- Corrected LCD spec: 11.6" 1080p widescreen, not 9.7" 4:3 iPad panel; noted
  the required LisaFPGA fork for offsetting the image to fit the case's
  screen opening
- Removed separate power switch hardware from BOM — the printed part sits
  over the LisaFPGA board's own switch; confirmed LCD mount clip qty is 4
- Removed incorrect FloppyEmu mention from BOM — LisaFPGA's built-in
  ESFloppy needs no separate hardware; documented the case's existing
  ESFloppy button cutouts and rear screen window, and noted a possible
  future front-mount revision
- Confirmed the 4 M3x4mm screws secure the LCD mount clips; front/back
  shell join is therefore snap-fit
- Documented layer height (0.2mm, 0.12mm + ironing for the logo plate)
- Clarified only the Lisa logo plate is included; the bezel's second badge
  holder is intentionally left blank to avoid distributing Apple's logo
- Added `Lisa_Mini_Manufacturer_Blank_Logo_Plate.obj` — the blank insert
  for the bezel's second badge holder
- Corrected supports guidance: the front shell also needs supports (under
  the logo plate badge holder, printed with a PETG support interface
  layer), not just the back; noted LCD clips + power switch print on the
  same plate as the front shell
- Added print orientation screenshots to PRINTING.md
- Rewrote ASSEMBLY.md into front/back/connect-and-close sections, and
  documented the barrel jack wiring, LCD controller mounting, and the
  quick-disconnect USB-C connectors between front- and back-mounted
  components
- Added 5 assembly photos and corrected the power switch step: the cap
  must be installed before the LisaFPGA board, since the board covers
  access to it afterward
- Added `Lisa_Mini_ESFloppy_Shroud.obj` — dresses up the rear ESFloppy
  screen opening; print in black, no supports needed
- Documented filament used: Polar Filament Retro Platinum PLA
- Filled in LCD mount clip orientation (LCD pushed all the way left,
  clips over the 4 mounting holes) and logo plate fit (press-fit, no
  glue — scale to 99% if too tight) in ASSEMBLY.md
- Documented ESFloppy shroud orientation (angles toward the top edge) and
  that it needs glue to hold (hot glue for removable, superglue for
  permanent) since the fit isn't perfect yet and an improved version may
  follow
- Added the 4 M3x4mm screws that secure the LisaFPGA board to the back
  shell's standoffs (8 total in the BOM now, with the LCD mount clip
  screws)
- Noted the low-profile USB-C cable and U-shaped HDMI adapter must be
  plugged into the LisaFPGA board before it's screwed down -- the case's
  tight clearance makes them hard to attach afterward
- Added a pre-assembly prerequisite: flash the LisaFPGA fork before
  closing up the case, since the low-profile USB-C cable carries power
  only, not data -- documented the reflash procedure (remove 4 screws,
  swap in a full USB-C power+data cable) for later updates
- Confirmed the front/back shell join is a plain press fit, with
  alignment bumps on the back shell and matching indentations on the
  front — closes out the last open TODO in ASSEMBLY.md
- Noted the power switch only switches the LisaFPGA, not the LCD — the
  plan is to pull the 12V input to power down both
- Confirmed the blank logo plate is also ironed at 0.12mm like the Lisa
  logo plate; simplified the small-parts orientation list (obvious from
  shape); noted no warping issues on the large shells with the Retro
  Platinum PLA
- Added 4 new photos to the README: Lisa Office System running on the
  assembled unit (new hero image), side profile, labeled back, and rear
  I/O closeup
- Published to Thingiverse and Creality Cloud; linked both from the
  README. Skipping MakerWorld/Bambu for now -- no Bambu printer has a bed
  large enough for the 330mm-wide shells
- Updated ASSEMBLY.md for the USB-capable fork: flashing steps (data cable,
  power switch on, approve the USB hub prompt), settings reset note, and a
  USB keyboard/mouse check in the final step
- Split the models into two designs plus shared parts: `common/`,
  `Lisa_Mini_With_ESFloppy_Screen_And_Buttons_On_Back/` (LisaFPGA untouched), and
  `Lisa_Mini_With_ESFloppy_Screen_And_Buttons_On_Front/` (ESFloppy screen, buttons, and lit
  power button moved to the front; requires soldering to the LisaFPGA)
- Added `Lisa_Mini_Back_LisaFPGA_SD_Slot_Covers.stl` and an updated
  `Lisa_Mini_Front.obj`, which replaces the old unbadged front; badged
  versions only going forward
- README, BOM, ASSEMBLY and PRINTING now explain how to pick a design
- Documented Design B extra parts: 3 push buttons, master rocker switch,
  header pins/Dupont wires, optional replacement 4-pin ESFloppy LCD
- Added a photographed step-by-step build for Design B (ESFloppy and power on the front), resized to web JPEGs under `images/design_b_assembly/`
- Split ASSEMBLY.md and BOM.md into standalone `docs/design_a/` and `docs/design_b/` guides; the old files now point to them
- Linked the YouTube assembly video (builds Design B, a superset of Design A's steps)

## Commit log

2026-09-08 feat: scaffold Lisa Mini public repo
    Print-ready OBJ files, parametric OpenSCAD source, and a docs framework
    (BOM, assembly, printing notes) for the Lisa Mini enclosure -- a
    3D-printable Apple Lisa-inspired case for a LisaFPGA board + 9.7" LCD.
    Claude-Session: https://claude.ai/code/session_016aGyqSXipK853hy5Nz3Cy8
    [Lisa_Mini_Back_LisaFPGA.obj, Lisa_Mini_Front_11.6_LCD_Mount_With_Logo_Plate_Holders.obj, Lisa_Mini_LCD_Mount_Clips.obj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]
2026-09-08 docs: fill in real BOM and note TinkerCAD post-processing step
    Add the actual LCD, LCD controller, buck converters, barrel jack, and
    screw hardware used in the build. Also clarify in the README that the
    print-ready OBJs went through significant TinkerCAD work (mounting
    points, port openings, LCD clips, logo plate) beyond what the .scad
    source models.
    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
2026-09-08 docs: add cabling to BOM for tight LisaFPGA fit
    Right-angle USB-C, U-shaped HDMI adapter, thin HDMI cable, and a 5V
    USB-C pigtail for the LCD controller -- all picked for clearance in
    the case's tight fit around the LisaFPGA board.
    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
2026-09-08 docs: note 5V USB-C controller issue and switch to 12V+buck converters
    The original LCD controller board didn't work reliably off 5V USB-C.
    It was later damaged during troubleshooting, so whether 5V USB-C was
    actually the cause is unconfirmed. Document the working power setup
    (12V barrel jack -> two buck converters) and flag direct 5V USB-C as
    unverified for anyone trying it.
    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
2026-09-08 docs: document bed size, orientation, and back-shell support requirement
    Front/back shells need a 350mm bed (model is 330mm wide) -- print front
    face down, back face up. Note that the back shell currently needs
    supports because of the skirt between the legs; a no-skirt variant
    that avoids most supports is possible but not yet made. Also cover the
    half-split option for smaller printers, with the tradeoff that the
    seam will be visible.
    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
2026-09-08 docs: remove stale no-supports/45deg claim from README
    The About section still said no overhangs > 45deg and no supports
    needed, contradicting the Printing section below it, which correctly
    notes the back shell needs supports.
    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
2026-09-08 docs: correct LCD spec and note required LisaFPGA fork
    The BOM and README described the LCD as a 9.7" 4:3 iPad-style panel,
    but the actual build uses an 11.6" 1080p widescreen display. The case's
    screen opening is still sized for the original 9.7" 4:3 window, so this
    build depends on a fork of the LisaFPGA software that offsets the
    displayed image to fit -- stock firmware won't position it correctly.
    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
2026-09-08 docs: fix power switch BOM and confirm LCD clip quantity
    The printed power switch part caps over the LisaFPGA board's own
    onboard switch -- no separate switch hardware is needed, so drop it
    from the BOM/assembly steps. Also confirm 4x LCD mount clips are used.
    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
2026-09-08 docs: clarify ESFloppy replaces FloppyEmu, no separate hardware needed
    The LisaFPGA's built-in ESFloppy emulator is why there's no FloppyEmu
    in the BOM -- remove that stale mention. Document the case's existing
    ESFloppy button cutouts and rear screen window in the README, and note
    that a front-mounted screen/buttons (via cable) is a possible future
    revision once ESFloppy support is finished, though the widescreen LCD
    may leave little room for it.
    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
2026-09-08 docs: fix BOM links to point at LisaFPGA fork, not this repo's README
    The relative ../README.md#software anchor resolved to this repo's own
    README instead of the fork -- point directly at
    https://github.com/wottle/LisaFPGA instead.
    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
2026-09-08 docs: confirm M3x4mm screws secure the LCD mount clips
    Closes the TODO in the BOM -- the 4 screws fasten the LCD mount clips
    holding the panel in place, which also confirms the front/back shell
    join itself is snap-fit (no screws left unaccounted for there).
    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
2026-09-08 docs: add logo plate layer height/ironing, clarify Apple logo omission
    Layer height is 0.2mm for all parts except the logo plate, which uses
    0.12mm with ironing for surface quality. Also clarify that the bezel's
    second badge holder (for an Apple logo) is deliberately left blank in
    this repo -- only the Lisa logo plate is included, to avoid
    distributing Apple's trademarked logo.
    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
2026-09-08 feat: add blank manufacturer logo plate, update docs
    Add Lisa_Mini_Manufacturer_Blank_Logo_Plate.obj -- the plain insert for
    the bezel's second badge holder, provided in place of an Apple logo
    plate to avoid distributing Apple's trademark. Reference it across
    README, BOM, ASSEMBLY, and PRINTING docs.
    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
    [Lisa_Mini_Manufacturer_Blank_Logo_Plate.obj]
2026-09-08 docs: front shell needs supports too, note shared print plate
    The front shell needs supports under the logo plate badge holder area
    (printed with a PETG support interface layer for quality, though it
    matters less since a logo plate covers that area). Correct the earlier
    back-only supports claim across README and PRINTING.md. Also note the
    LCD mount clips and power switch print alongside the front shell,
    since the screen cutout leaves plenty of bed space for them.
    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
2026-09-08 docs: add print orientation screenshots to PRINTING.md
    Slicer screenshots showing the back shell's support setup and the
    front shell plated with the LCD mount clips and power switch in the
    screen cutout's open bed space.
    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
2026-09-08 docs: restructure assembly steps, remove standalone power switch step
    Split ASSEMBLY.md into front assembly, back assembly, and
    connect-and-close sections. Fold the power switch install into
    closing the shells (it snaps over the LisaFPGA's own switch, no
    separate step needed). Add the LCD controller board mounting
    (double-sided tape to the back of the LCD panel), the barrel jack
    wiring split to the two buck converters, and the LisaFPGA standoff
    screw-down. Document quick-disconnect USB-C connectors between the
    buck converters and the LisaFPGA/LCD controller in both BOM.md and
    ASSEMBLY.md -- this is what lets the front- and back-mounted
    components separate cleanly.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
2026-09-08 docs: add 5 assembly photos, fix power switch install order
    Wire in the 5 assembly photos: LCD + controller board mounting, back
    shell power wiring, power switch cap orientation, LisaFPGA board
    install, and the HDMI/5V connections between back and front shells.
    The power switch photo reveals an ordering constraint that wasn't
    previously captured: the switch cap must be snapped into the rear
    shell BEFORE the LisaFPGA board is installed, since the board covers
    that mounting point afterward. Move it back to its own step ahead of
    the LisaFPGA install.
    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
2026-09-08 feat: add ESFloppy shroud, wire into BOM/assembly/printing docs
    Add Lisa_Mini_ESFloppy_Shroud.obj -- dresses up the rear ESFloppy
    screen opening, which currently sits well below the back surface.
    Print in black (visible on the case exterior), no supports needed.
    Reference it across README, BOM, PRINTING, and add its own install
    step in ASSEMBLY.md ahead of the power switch cap.
    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
    [Lisa_Mini_ESFloppy_Shroud.obj]
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2026-09-08 docs: fill in LCD mount clip orientation and logo plate fit
    LCD seats pushed all the way left in the bezel, clips go over the 4
    mounting holes and screw down. Logo plates are press-fit, no glue --
    scale to 99% and reprint if a plate is too tight to seat.
    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
2026-09-08 docs: document ESFloppy shroud orientation and glue requirement
    The shroud needs to angle toward the top edge of the case, and the
    press-fit alone may not hold it -- recommend hot glue (removable) or
    superglue (permanent). Note the current fit isn't perfect (exposes
    too much of the area below the ESFloppy LCD) and may be replaced by
    an improved shroud later, so hot glue avoids having to reprint the
    back shell in the meantime.
    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
2026-09-08 docs: add the LisaFPGA mounting screws to the BOM
    4 more M3x4mm screws secure the LisaFPGA board to the back shell's
    standoffs, alongside the existing 4 for the LCD mount clips (8 total).
    Update ASSEMBLY.md's LisaFPGA install and shell-join steps to match --
    the join step's snap-fit reasoning now accounts for both screw sets.
    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
2026-09-08 docs: attach LisaFPGA's USB-C/HDMI connectors before screwing it down
    The low-profile right-angle USB-C cable and U-shaped HDMI adapter need
    to be plugged into the LisaFPGA board before it's mounted -- the
    case's tight clearance makes both hard or impossible to attach once
    the board is screwed to the standoffs.
    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
2026-09-08 docs: flash LisaFPGA fork before assembly, document reflash procedure
    Once assembled, the LisaFPGA's USB-C port only has the low-profile
    power cable connected (no data), so software can't be updated without
    partial disassembly. Add flashing the fork as a prerequisite in
    ASSEMBLY.md's "Before you start", link to it from the README's
    Software section, and document how to reflash later: remove the 4
    LisaFPGA screws, unplug the low-profile power cable, and connect a
    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
2026-09-08 docs: confirm shell join is a press fit with alignment bumps
    The front and back shells simply press together -- no snap-fit
    mechanism, just a plain press fit, held in place by small bumps on
    the back shell that align with matching indentations on the front.
    This closes out the last open TODO in ASSEMBLY.md.
    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
2026-09-08 docs: fix README's stale snap-fit/no-glue assembly summary
    Match the corrected ASSEMBLY.md terminology (press fit with alignment
    bumps, not snap-fit) and drop "no glue required" -- the ESFloppy
    shroud does need glue.
    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
2026-09-08 docs: note the power switch only covers the LisaFPGA, not the LCD
    There's no separate power switch for the LCD -- the plan is to pull
    the 12V input when not in use, which cuts power to both the LisaFPGA
    and the LCD controller.
    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
2026-09-08 docs: close out remaining PRINTING.md TODOs
    Blank logo plate gets the same 0.12mm + ironing treatment as the Lisa
    logo plate. Simplify the small-parts orientation list since they're
    obvious from shape. No warping issues on the large front/back shells
    with Retro Platinum PLA -- drop the empty "known print issues" section.
    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
2026-09-08 docs: add Lisa Office System, side profile, and rear photos to README
    Swap in the Lisa Office System shot as the hero image, and add a
    2x2 gallery below it: side profile (showing the wedge shape and
    L-shaped leg), the labeled back panel (PROGRAM, ESProfile/ESFloppy
    reset, main power), and a rear I/O closeup, plus the original angled
    front shot.
    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
2026-09-08 docs: link Thingiverse and Creality Cloud listings
    Skip MakerWorld/Bambu for now -- no Bambu printer has a bed large
    enough for the 330mm-wide front/back shells.
    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
2026-10-08 Add front-mounted ESFloppy design, split models into common and per-design folders
    Models now live in common/, an ESFloppy-on-back folder (stock, LisaFPGA
    untouched) and an ESFloppy-on-front folder (requires soldering to the
    LisaFPGA). Docs explain how to pick a design, Design B has a photographed
    step-by-step build, and the USB-capable fork flashing steps are documented.
    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
    [Lisa_Mini_Back_LisaFPGA.obj, Lisa_Mini_Back_LisaFPGA_ESFloppy_Moved_To_Front.obj, Lisa_Mini_Back_LisaFPGA_SD_Slot_Covers.stl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]
2026-10-08 docs: clarify Design A steps, power controls, and buck converter setup
    Label steps 1-9 as Design A, distinguish the power switch from the Lisa
    Power button, add the switch cap and buck converter 5V adjustment to the
    back-case steps, and fold the board install details into Design B step B7.
    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
2026-10-08 docs: split assembly guide and BOM into per-design files
    Design A and Design B each get a standalone ASSEMBLY.md and BOM.md under
    docs/design_a and docs/design_b. The old docs/ASSEMBLY.md and docs/BOM.md
    now point to them, and the README links to each pair.
    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
2026-10-08 docs: reuse Design A LCD mounting photo in Design B step 1
    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
2026-10-08 docs: note LED polarity in Design B power button wiring
    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
2026-10-08 docs: state which LED5 pad is positive in Design B
    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
2026-10-25 Split back shell skirt into its own part so the back prints without supports
    Adds with/without cable cutout skirt variants for both designs, to be glued on after printing, and updates the README, BOMs, printing notes and assembly guides.
    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
